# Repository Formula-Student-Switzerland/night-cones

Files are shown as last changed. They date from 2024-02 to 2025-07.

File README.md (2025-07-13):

# FSCH Night-Cones
FSCH night-cones

The FSCH Night-Cones are ESP8266 controlled RGB lights for the illumination of a formula student track. The project is described in detail in the documentation available in the `doc` folder. 

## Hardware

### PCBs

#### NC1-1
Nightcone main PCB

##### NC1-1AA
Initial prototype PCB as ordered

##### NC1-1AB
Modifications to the assembly of the initial prototype

##### NC1-1BA
PCB version for first series production run

##### NC1-1BB
Modifications to first series prodction run, version used in FSCH 2024 night skidpad

##### NC1-1CA
All issues from previous versions implemented. 
This version should be used for reproduction of the NightCones. 

##### Assembly variants
Multiple versions of the WS2813 LED exist, which have a slightly different pinout. This is covered by the different assembly variants of the PCB. 

###### NC1-11
WS2813B-B: 
* Pin 1 is VCC
* DATA_IN is connected to BACKUP_OUT
* VCC pin is supplied with a 270 Ohm resistor and bypassed with a 1uF capacitor

###### NC1-12
WS2813B-V5:
* Pin 1 is BO
* The BO pin and is connected to BACKUP_OUT

###### NC1-13
WS2813C:
* Pin 1 is VCC
* DATA_IN is connected to BACKUP_OUT
* VCC pin is supplied with a 270 Ohm resistor and bypassed with a 1uF capacitor

###### NC1-14
WS2813E:
* Pin 1 is NC
* DATA_IN is connected to BACKUP_OUT

#### NC1-2
Testadapter for automated PCB test of the main nightcone PCB NC1-1. Only index NC1-2BA exists, which is intended to be used for NC1-1B*. 

#### NC1-3
Programming adapter to program the nightcone PCB standalone as well as mounted in the enclosure. To program, a USB-A to UAB-B cable and a 6-pin RJ-11 TagConnect cable are required. 

### Housing
The current housing is designed to be printed out of transparent PETG. It consists of three parts that are printed independently and glued together afterwards. 

## Software
The current software state includes a running software on the cone. Currently, there exists no software running on server side.

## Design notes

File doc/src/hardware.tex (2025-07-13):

\section{Hardware}

\FloatBarrier

\subsection{Overview}

\FloatBarrier

\subsection{Controller}
\label{sec_ctrl}
An ESP8266 on a module is selected as microcontroller. The module is used as it already contains the matching network and either an antenna or antenna connector. 
The usage of an ESP32 was considered as well but finally rejected due to the higher cost. 

Three options are considered for the module: ESP-01S, ESP-07S and ESP-12F. \autoref{tab_ESP_modules} lists the modules and their most important specifications. 

\begin{table}[h!]
    \centering
    \begin{zebratabular}{llll}
    \rowcolor{gray} 
        Module  & GPIO  & ADC pin   & Antenna \\
        ESP-01S & 4     & No        & internal \\
        ESP-07S & 11    & No        & external \\
        ESP-12F & 17    & No        & internal \\
    \end{zebratabular}
    \caption[Overview of ESP6288 modules]
            {Overview of ESP6288 modules \cite{AIThinker:ESP_01S} \cite{AIThinker:ESP_07S} \cite{AIThinker:ESP_12F}}
    \label{tab_ESP_modules}
\end{table}

It is possible to solder any of the modules that is listed in \autoref{tab_ESP_modules} on the PCB. The ESP-07S can be soldered on the same footprint as the ESP-12F. The ESP-01S footprint could be fitted inside the ESP-12F footprint. Special car must be taken in that case, as the ESP-07S has an exposed pad. Only the GND pin of the ESP-01S is allowed to touch the area of the exposed pad to prevent short-circuits when the ESP-07S is mounted. \cite{AIThinker:ESP_07S}\cite{AIThinker:ESP_12F}

The ESP module is powered directly from the \qty{3.3}{\volt} supply. The design of the \qty{3.3}{\volt} supply is documented in \secref{sec_power_3V3}. 

The EN pin and the RST pin are pulled to \qty{3.3}{\volt} with a pull-up resistor each. The GPIO pinout is listed in \autoref{tab_ESP_pinout}. 

\begin{table}[h!]
    \centering
    \begin{zebratabular}{lllll}
        \rowcolor{gray} 
        Signal      & ESP-01S   & ESP-07S   & ESP-12F   & Description \\
        DATA        & GPIO0     & GPIO15    & GPIO15    & LED data \\
        KILL        & GPIO2     & GPIO13    & GPIO13    & Turn-off command \\
        HALL        & N/A       & GPIO14    & GPIO14    & Presence detection from hall sensor \\
        VBAT\_MON   & N/A       & ADC       & ADC       & Battery voltage monitor \\
    \end{zebratabular}
    \caption{ESP module pinout}
    \label{tab_ESP_pinout}
\end{table}

\FloatBarrier

\subsection{LED}
\label{sec_LED}
Addressable NeoPixel acp{LED} of the type WS2813 from WorldSemi are used to illuminate the cone. Four \acp{LED} are evenly distributed on the top side of the PCB to illuminate the enclosure of the NightCone. A total of 16 \acp{LED} are aligned in the shape of a circle on the bottom side. The purpose of those \acp{LED} is the illumination of the ground around the cone and the cone from above. 

Each NeoPixel \ac{LED} contains a controller and three single \acp{LED} in the colors red, green and blue. The brightness of each LED can be set through an interface. On the interface a bit is represented by a pulse. The value of the bit is encoded in the pulse length. A reset command is sent by pulling the data line low for an certain time $t_{reset}$. \autoref{fig_neopixel_bit} shows the signal shape of 0s, 1s and the reset pulse. The specific timing depends on the LED type and is listed in \autoref{tab_neopixel_timing}. \cite{Worldsemi:WS2813B-B}\cite{Worldsemi:WS2813B-V5}\cite{Worldsemi:WS2813C}\cite{Worldsemi:WS2813E}

\begin{figure}[h!]
    \centering
    \begin{tikztimingtable}
        0s    & 0.2L25{0.6H1.4L}0.2H\\
        1s    & 0.2L25{1.4H0.6L}0.2H\\
        Reset & 0.2H50L0.2H\\
    \end{tikztimingtable}
    \caption[NeoPixel bits, timing not representative]
            {NeoPixel bits, timing not representative, see \autoref{tab_neopixel_timing} for exact timing}
    \label{fig_neopixel_bit}
\end{figure}

\begin{table}[h!]
    \centering
    \begin{zebratabular}{lllllll}
        \rowcolor{gray}
        LED type    & $t_{0_H}$ [\si{\nano\second}] & $t_{0_L}$ [\si{\nano\second}] & $t_{1_H}$ [\si{\nano\second}] & $t_{1_L}$ [\si{\nano\second}] & $t_{Reset}$ [\si{\micro\second}]  & Pin 1 \\
        WS2813B-B   & 220 \ldots 380                & 580 \ldots 1600               & 580 \ldots 1600               & 220 \ldots 420                & > 280                             & VCC   \\
        WS2813B-V5  & 220 \ldots 380                & 580 \ldots 1000               & 580 \ldots 1600               & 580 \ldots 1000               & > 280                             & BO    \\
        WS2813C     & 220 \ldots 380                & 580 \ldots 1600               & 580 \ldots 1600               & 220 \ldots 420                & > 280                             & VCC   \\
        WS2813E     & 220 \ldots 380                & 580 \ldots 1600               & 580 \ldots 1600               & 220 \ldots 420                & > 280                             & NC    \\
    \end{zebratabular}
    \caption[LED timing overview]
            {LED timing overview \cite{Worldsemi:WS2813B-B}\cite{Worldsemi:WS2813B-V5}\cite{Worldsemi:WS2813C}\cite{Worldsemi:WS2813E}}
    \label{tab_neopixel_timing}
\end{table}

Each \ac{LED} has an internal buffered shift-register with a length of \qty{24}{\bit}. Every bit that is received shifts the content of the register for \todo{better word (um)} one bit. The last bit that is shifted out of the register is transmitted to the successive \ac{LED} in the chain. When a reset signal is received, the content of the shift-register is loaded into the buffer and the brightness of the three colored \acp{LED} is updated. The register definition is shown in \autoref{tab_neopixel_register}. \cite{Worldsemi:WS2813B-B}\cite{Worldsemi:WS2813B-V5}\cite{Worldsemi:WS2813C}\cite{Worldsemi:WS2813E}

\begin{table}[h!]
    \centering
    \begin{tabular}{|l|l|l|l|l|l|l|l|l|}
        \hline
        Bit     & 1  & 2  & 3  & 4  & 5  & 6  & 7  & 8  \\
        \hline
        Data    & G7 & G6 & G5 & G4 & G3 & G2 & G1 & G0 \\
        \hline
        \hline
        Bit     & 9  & 10 & 11 & 12 & 13 & 14 & 15 & 16 \\
        \hline
        Data    & R7 & R6 & R5 & R4 & R3 & R2 & R1 & R0 \\
        \hline
        \hline
        Bit     & 17 & 18 & 19 & 20 & 21 & 22 & 23 & 24 \\
        \hline
        Data    & B7 & B6 & B5 & B4 & B3 & B2 & B1 & B0 \\ 
        \hline
    \end{tabular}
    \caption{NeoPixel register definition}
    \label{tab_neopixel_register}
\end{table}

The advantage of the WS2813 type over the widely used WS2812 is the additional backup input. The input of each \ac{LED} is also connected to the backup input of the next \ac{LED} in the chain. This allows the chain to continue operation even when a \ac{LED} has failed completely. The chain continues to operate with up to half of the \acp{LED} failed, as long as there are no successive failed \acp{LED}. On some \ac{LED} types a separate backup output exists on pin 1. Refer to \autoref{tab_neopixel_timing} for this information. 

\subsection{Failsafe}
\label{sec_failsafe}
\ReqRef{R:Failsafe} requires the \acp{LED} to illuminate in a controlled way after a controller failure. The simplest way to control the \acp{LED} is to send 1's followed by a reset pulse. This causes the \acp{LED} to light up white with the highest intensity. To ensure that all \acp{LED} turn on, the number of bits sent must be at least the number of bits per \ac{LED} multiplied by the number of \acp{LED}. A missing-pulse detector with an edge detector is used to detect a controller failure. Depending on the state of this detector, the signal from the controller or the failsafe signal is selected for the \acp{LED}. 

The controller is powered with a voltage of \qty{3.3}{\volt}, which results in the same level for the output signals. The \acp{LED} are powered by the \qty{5.2}{\volt} supply and therefore expect an input signal with a similar voltage. A level-shifter converts the signal from \qty{3.3}{\volt} to \qty{5.2}{\volt} and also inverts the signal. An edge-detector avoids that a static signal triggers the missing-pulse detector. The inverter of the edge-detector is used to recondition the input signal and invert it again. The edge-detector generates a low pulse when a rising edge is detected. \autoref{fig_failsafe_edge}

\begin{figure}[h!]
    \centering
    
    \caption{Levelshifter and edge detector}
    \label{fig_failsafe_edge}
\end{figure}

The missing-pulse detector is built with a XL555, which is a pin-compatible \ac{CMOS} derivate of the NE555 timer. \todo{reference to XL555 datasheet} The timing capacitor C10 is continuously charged by R13. The low pulse from the edge-detector discharges the capacitor through D10 and R20. R20 limits the current to protect the output of the edge-detector. In case D10 is not able to discharge C10 quick enough, Q4 can be added to increase the discharge current. The output of the edge-detector is also connected to the TRIG input of the timer and sets the internal flipflop when a pulse is detected. When the capacitor voltage reaches the CONT voltage, which is $\frac{2}{3}$ of the supply voltage, the flipflop of the timer is reset, which is interpreted as controller-failure. \autoref{fig_failsafe_missing_pulse}

\begin{figure}[h!]
    \centering
    
    \caption{Missing-pulse detector}
    \label{fig_failsafe_missing_pulse}
\end{figure}

An astable multivibrator with a XL555 generates the pulse pattern for a series of 1s. The timing requirements depends on the \ac{LED} type. \autoref{tab_neopixel_timing} shows the timing requirements for each \ac{LED} type that can be used. The formula for the timing as astable multivibrator is inaccurate in the frequency range that is used to generate the data pulse. \todo{Reference to XL555 datasheet} Therefore the component values for the oscillator were iterated on a test circuit using a TLC555 which is very similar to the XL555 that is used. The resulting values are listed in \autoref{tab_failsafe_bit_values}. The bit signal is fed into a ripple counter to count the number of bits and generate the reset pulse. \todo{Number of stages in the reset counter} \autoref{fig_failsafe_bit_counter}

\begin{table}[h!]
    \centering
    \begin{zebratabular}{llllll}
        \rowcolor{gray}
        LED &
        $t_{1_H}$ &
        $t_{1_L}$ &
        R17 &
        R19 &
        C11 \\
        B-B, C, E &
        \qty{1.09}{\micro\second} &
        \qty{320}{\nano\second} &
        \qty{1.5}{\kilo\ohm}   &
        \qty{270}{\ohm}        &
        \qty{470}{\nano\farad} \\
        B-V5 &
        \qty{1.09}{\micro\second} &
        \qty{790}{\nano\second} &
        \qty{910}{\ohm} &
        \qty{1.2}{\kilo\ohm} &
        \qty{470}{\nano\farad} \\
    \end{zebratabular}
    \caption{Component values for the astable multivibrator, obtained from TLC555 test circuit iteration}
    \label{tab_failsafe_bit_values}
\end{table}

\begin{figure}[h!]
    \centering
    
    \caption{Bit-pulse generator with counter for reset generation}
    \label{fig_failsafe_bit_counter}
\end{figure}

The data pulse and the reset signal are combined to the failsafe signal with an AND gate. A multiplexer (74LVC1G157) selects either the signal from the controller or the failsafe signal to send to the \acp{LED} based on the state of the missing-pulse detector. 

\begin{figure}[h!]
    \centering
    
    \caption{Signal selector}
    \label{fig_failsafe_mux}
\end{figure}

\FloatBarrier

\subsection{Battery}
\label{battery}
The NightCone is powered by a single \ac{LiIon} battery cell. The cell is mounted in the center of the NightCone. 

To design the required battery capacity, the energy consumption of each component is calculated. The efficiency $\eta_{5V2}$ and $\eta_{3V3}$ of each voltage converter is assumed to be 0.9. 

The average current consumption of the ESP module is \qty{71}{\milli\ampere} at a supply voltage of \qty{3.3}{\volt}. \cite{AIThinker:ESP_12F}
\begin{align}
    P_{ESP} = \dfrac{V_{ESP} \cdot I_{ESP}}{\eta_{5V2} \cdot \eta_{3V3}} = \dfrac{\qty{3.3}{\volt} \cdot \qty{71}{\milli\ampere}}{0.9 \cdot 0.9} = \qty{289.3}{\milli\watt}
\end{align}

The current of a single \ac{LED} is up to \qty{16}{\milli\ampere} for all three colors. \cite{Worldsemi:WS2813E}
\begin{align}
    P_{LED} = \dfrac{V_{LED} \cdot I_{LED} \cdot 3 \cdot n_{LED}}{\eta_{5V2}} = \dfrac{\qty{5.2}{\volt} \cdot \qty{16}{\milli\ampere} \cdot 3 \cdot 20}{0.9} = \qty{5.547}{\watt}
\end{align}

As the current consumption of the failsafe circuit is assumed to be much smaller than that of the \acp{LED} it is neglected for the energy estimation. 

The minimum oparation time is defined in \ReqRef{R:Time}. 
\begin{align}
    W = \left(P_{ESP} + P_{LED}\right) \cdot t = \left(\qty{289.3}{\milli\watt} + \qty{5.547}{\watt}\right) \cdot \qty{4}{\hour} = \qty{23.35}{\watt\hour}
\end{align}
\begin{align}
    Q = \dfrac{W}{V_{nom}} = \dfrac{\qty{23.35}{\watt\hour}}{\qty{3.6}{\volt}} = \qty{6.31}{\ampere\hour}
\end{align}

A capacity of \qty{6.31}{\ampere\hour} would require a 26650 cell. As the cone is not expected to be set to the maximum brightness for all three colors, a capacity of about \qty{5}{\ampere\hour} is expected to be sufficient. This allows the use of a 21700 cell, which reduces the cost of the battery solution. A 18650 cell could also fit in the enclosure, but would only be available with a capacity of \qty{3}{\ampere\hour}, which is assumed to be insufficient. 

The cell is mounted in the center of the NightCone. The \ac{PCB} includes an opening in the center for the cell to fit through. Nickel strips are spotwelded to the cell. The strips are soldered to solder pads to connect the battery to the electronics. The positive lead is connected soldered to the top side of the \ac{PCB}, the negative lead to the bottom side. 

\subsection{Battery Management System}
\label{sec_bms}
The battery management system is pretty simple using a two IC solution. The used DW01A \cite{Puolop:DW01A} is a low cost \ac{LiIon} protection IC. It protects the battery from the following issues: 
\begin{itemize}
	\item Overvoltage at $\qty{4.3(0.05)}{\V}$  after $\qtyrange{110}{200}{\ms}$
	\item Undervoltage at $\qty{2.50(0.10)}{\V}$after $\qtyrange{55}{200}{\ms}$
	\item Overcurrent
\end{itemize}
This covers requirement \ReqRef{R:Current} and partially \ReqRef{R:BMS}. The overtemperature protection is done in the charger and therefore only available during charging. 

The overcurrent protection is realized using the voltage drop over the two AO3400A \cite{AOSMD:AO3400A}. The DW01A IC features two types of over current protection. 

The fast over current protection triggers at nominal $\qty{1.36}{\V}$ with a blanking time of $\qtyrange{400}{600}{\ms}$. This leads to the following thresholds: 
\begin{align}
	I_\mathrm{SC;fast,min} &= \frac{V_\mathrm{SC,fast,min}}{2\cdot R_\mathrm{AO3400A,max}}=\frac{\qty{0.82}{\V}}{2\cdot\qty{48}{\milli\ohm}}=\qty{8.5}{\A}\\
		I_\mathrm{SC;fast,typ} &= \frac{V_\mathrm{SC,fast,typ}}{2\cdot R_\mathrm{AO3400A,typ}}=\frac{\qty{1.36}{\V}}{2\cdot\qty{24}{\milli\ohm}}=\qty{28.3}{\A}\\
		I_\mathrm{SC;fast,max} &= \frac{V_\mathrm{SC,fast,max}}{2\cdot R_\mathrm{AO3400A,typ}}=\frac{\qty{1.75}{\V}}{2\cdot\qty{24}{\milli\ohm}}=\qty{36.5}{\A}\\
\end{align}

\begin{figure}[h!]
    \centering
    
    \caption{Battery management system}
    \label{fig_bms}
\end{figure}

The slow over current protection triggers at nominal $\qty{150(20)}{\milli\V}$ after a blanking time of $\qtyrange{7}{20}{\ms}$. This leads to the following values: 
\begin{align}
	I_\mathrm{SC;slow,min} &= \frac{V_\mathrm{SC,slow,min}}{2\cdot R_\mathrm{AO3400A,max}}=\frac{\qty{130}{\milli\V}}{2\cdot\qty{48}{\milli\ohm}}=\qty{1.4}{\A}\\
		I_\mathrm{SC;slow,typ} &= \frac{V_\mathrm{SC,slow,typ}}{2\cdot R_\mathrm{AO3400A,typ}}=\frac{\qty{150}{\milli\V}}{2\cdot\qty{24}{\milli\ohm}}=\qty{3.1}{\A}\\
		I_\mathrm{SC;slow,max} &= \frac{V_\mathrm{SC,slow,max}}{2\cdot R_\mathrm{AO3400A,typ}}=\frac{\qty{170}{\milli\V}}{2\cdot\qty{24}{\milli\ohm}}=\qty{3.5}{\A}\\
\end{align}

If the maximum current is $I_\mathrm{max}=\frac{P_\mathrm{ESP}+P_\mathrm{LED}}{V_\mathrm{bat,min}}=\frac{\qty{289.3}{\milli\W} + \qty{5.547}{\W}}{\qty{2.5}{\V}}=\qty{2.33}{\A}$, the current threshold is exceeded, if the resistance of both MOSFETS is at the maximum value. This must be extensively tested. 

The resettable fuse acts as a last resort, if the DW01A is malfunctioning.

\FloatBarrier

\subsection{Charger}
\label{sec_charger}

The cone can be charge by using three screws as connectors on the outside to fulfil \ReqRef{R:Charging}. Two of the three circumferentially distributed screws must be connected to a voltage of $\qtyrange{5.25}{6.5}{\V}$, as it can be seen in Figure \ref{fig_chg_connection}. 
\begin{figure}[h!]
	\centering
	
	\caption{Charging pin connection}
	\label{fig_chg_connection}
\end{figure}
The $\qty{1.5}{\A}$ fuse protects the charging circuit. The six shottky rectifier diodes allow to use any pin for positive and negative supply. The two $\qty{1}{\ohm}$ resistors are used to reduce the required voltage drop inside the charging IC and to act as linear impedance for the $\qty{6.8}{\V}$ transient voltage suppression diode. The diode has a reverse stand-off voltage of $\qty{5.8}{\V}$ and a minimum breakdown voltage of $\qty{6.45}{\V}$. 
This allows a maximum input voltage of 
\begin{align}
	V_\mathrm{in,max} &= V_\mathrm{R,TVS} + 2\cdot V_\mathrm{f,SS34} = \qty{5.8}{\V}+ 2\cdot \qty{0.35}{\V}=\qty{6.5}{\V}\\
	V_\mathrm{in,min,end} &= V_\mathrm{bat,max} + V_{drop, TP4056} + 2\cdot V_{f,SS34} = \qty{4.2}{\V} + \qty{0.03}{\V} + 2\cdot \qty{0.35}{\V} = \qty{4.93}{\V}
\end{align}
The voltage drop on the voltage reduction resistor can be neglected for the first two cases because the maximum voltage must be followed also for the final charge phase, where the current converges to zero and the same is the case for the minimal voltage when finishing charging. 
The voltage drop is considered in the following case for the minimum voltage at full charging current at the highest voltage:
\begin{align}
	V_\mathrm{in,min,charge} &= V_\mathrm{bat,charge} + V_\mathrm{drop, TP4056} + 2\cdot V_\mathrm{f,SS34} + R \cdot I_\mathrm{chg}\\
	&= \qty{4.1}{\V} + \qty{0.03}{\V} + 2\cdot \qty{0.35}{\V} + \qty{0.5}{\ohm} \cdot  \qty{0.78}{\A} = \qty{5.22}{\V}
\end{align}

\begin{figure}[h!]
    \centering
    
    \caption{Charging rectifier and input protection}
    \label{fig_chg_input}
\end{figure}

The charging IC TP4056 \cite{MSKSEMI:TP4056} monitors the cell temperature during the charging process by evaluating the voltage drop of the used $\qty{10}{\kilo\ohm}$ \ac{NTC}. This covers the missing part of \ReqRef{R:BMS}. The voltage at the Temp pin is evaluated as ratio to the supply voltage. The operative range is $\num{0.45} \cdot \mathrm{VCC}$ to $\num{0.8} \cdot \mathrm{VCC}$. The resistor divider is designed to operate in a temperature range from $\qtyrange{5}{50}{\celsius}$. The resistors $R_5$ and $R_7$ are derived using these formulas: 
\begin{align}
R_7 &= \frac{R_\mathrm{th,low}\cdot R_\mathrm{th,high}}{(V_\mathrm{th,low}-1)\cdot R_\mathrm{th,high} + \left(\frac{V_\mathrm{th,low}}{V_\mathrm{th,high}}-V_\mathrm{th,low}\right)\cdot R_\mathrm{th,low}}\\
R_5 &= R_7\cdot R_\mathrm{th,low}\cdot \frac{1-V_\mathrm{th,high}}{V_\mathrm{th,high}\cdot (R_7+R_\mathrm{th,low})}
\end{align}
The resulting values where then adapted to use resistors already used in other parts of the schematic, which also matched quite well. 

\begin{figure}[h!]
    \centering
    
    \caption{Charger}
    \label{fig_charger}
\end{figure}

The charging current is set to $\qty{780}{\mA}$ by using the $\qty{1.5}{\kilo\ohm}$ resistor. The charger has a trickle current feature that charges the battery with a low current of $\qty{130}{\milli\A}$ if the battery voltage is below $\qty{2.9}{\V}$. \\
In the schematic, both \acp{LED} are marked as green. \ac{LED} D6 is replaced by a red \ac{LED}. The functions of the \acp{LED} are summarized in the following table

\begin{table}[h!]
    \centering
    \begin{zebratabular}{lll}
        \rowcolor{gray}
        Charging State &
        LED Green &
        LED Red \\
        Charging & off & on \\
        Charging terminated & on & off\\
        Temp error, no power or battery & off &off\\
        No battery & on & flashing ($\qtyrange{1}{4}{\s}$)
    \end{zebratabular}
    \caption{Charger LED Signals}
    \label{tab_chg_led}
\end{table}

\FloatBarrier

\subsection{On/off controller}
\label{sec_onoff}

As \ReqRef{R:Rain} requires the cone to be able to operate in rain , it must be possible to turn the NightCone on and off without opening it. To fulfill this requirement, one method to enable the NightCone and two methods to disable it are implemented. The hall sensor U30 (UHE4913) detects the presence of a magnet. When a magnet is detected, the output of the sensor is pulled low. This pulls the enable input of the boost converter U28 towards the battery voltage, which enables the converter. As the hall sensor is directly connected to the battery and therefore always powered, a sensor with a low operating current must be chosen. The selected boost converter (TPS61023) completely disconnects the output from the input when the converter is disabled. This is necessary because the output voltage of a boost converter is always at least slightly lower than the input voltage due to the body diode of the highside \ac{MOSFET}. \cite{TI:TPS61023}. \todo{Check link to TPS61023 datasheet}

The controller can send a KILL signal to the on/off controller. To ensure, that a static high signal is not able to shut down the NightCone, the signal is AC coupled and rectified. To disable the NightCone, a series of pulses must be sent to the KILL signal which charges the capacitor C71. When the threshold voltage of Q10 is reached, the \qty{5.2}{\volt} converter is disables by pulling the EN signal low. 

The requirement \ReqRef{R:Disable} demands an analog shutdown device. This is implemented by supervising the voltage on the charging input. When a voltage is detected, Q9 pulls the EN signal to GND, which disables the \qty{5.2}{\volt} converter. The threshold level can be adjusted by changing the voltage divider R94 and R96. This ensures that the NightCone is automatically disabled when it is connected to the charging station. 

During development and debugging it is advantageous to allow the operation of the NightCone while the battery is being charged. To allow this operation mode, the signal of the hall sensor is prioritized over both turn off signals. This means, that the NightCone can not be turned off when the presence of a magnet is detected. For the schematic of the on/off controller, see \autoref{fig_onoff}. 

\begin{figure}[h!]
    \centering
    
    \caption{On/off controller}
    \label{fig_onoff}
\end{figure}

\FloatBarrier

\subsection{Converter \qty{5.2}{\volt}}
\label{sec_power_5V2}

\begin{figure}[h!]
    \centering
    
    \caption{\qty{5.2}{\volt} converter}
    \label{fig_power_5V2}
\end{figure}

\FloatBarrier

\subsection{Converter \qty{3.3}{\volt}}
\label{sec_power_3V3}

\begin{figure}[h!]
    \centering
    
    \caption{\qty{3.3}{\volt} converter}
    \label{fig_power_3V3}
\end{figure}

\FloatBarrier

\subsection{Testing}
The initial prototypes (index A) are manually tested using the protocol in \todo{Add test protocol to annex and refer to it}. 

For the production run with index B, a test adapter is built to allow for automated testing. 

\begin{table}[h!]
    \centering
    \begin{zebratabular}{lllll}
        \rowcolor{gray}
        Testpoint   & Signal    & Measure       & Supply        & Short         \\
        TP1         & Data      &               & Pulse 3V3     & GND           \\
        TP2         & GPIO0     &               & Programmer    & GND           \\
        TP3         & SDA       &               &               &               \\
        TP4         & SCL       &               &               &               \\
        TP5         & KILL      &               & Pulseburst 3V3&               \\
        TP6         & TXD       &               & Programmer    &               \\
        TP7         & RXD       &               & Programmer    &               \\
        TP8         & RST       & Voltage       & Programmer    & GND           \\
        TP9         & TEMP      & Voltage       &               &               \\
        TP10        & FS\_ACT/  & Voltage       &               &               \\
        TP11        & DATA\_FS  & Pulsewidth    & Pulse 5V      & GND           \\
        TP12        & FS\_PULSE & Pulsewidth, f &               &               \\
        TP13        & FS\_DATA  & Pulsewidth, n &               &               \\
        TP14        & +5V\_CHG  & Voltage       &               &               \\
        TP15        & CHG\_A    &               & Charge +/-    &               \\
        TP16        & CHG\_B    &               & Charge +/-    &               \\
        TP17        & CHG\_C    &               & Charge +/-    &               \\
        TP18        & +VBAT     & Voltage Bat   & Battery +     & Load to -VBAT \\
        TP19        & -VBAT     & Voltage Bat   & Battery -     & Load to +VBAT \\
        TP20        & +5V2      & Voltage       &               & Load to GND   \\
        TP21        & +3V3      & Voltage       &               & Load to GND   \\
        TP22        & GND       &               &               &               \\
        TP23        & HALL/     & Voltage       &               & GND           \\
        TP24        & VBAT\_MON & Voltage       &               &               \\
    \end{zebratabular}
    \caption{NC1-1B test point overview}
    \label{tab_test_point}
\end{table}

\FloatBarrier

\subsection{Modifications from index AA to index AB}

\subsubsection{Feedforward capacitor in \qty{5.2}{\volt} and \qty{3.3}{\volt} supply}
The feedforward capacitors in the feedback networkof the two converters are not meant to be mounted. It must either be removed or a value must be selected to ensure loop stability. 

\subsubsection{Charging LED color}
To reduce the cost of the first prototypes, the color of the charging \ac{LED} was changed to green. For correct operation, it needs to be changed to red. 

\subsection{Modifications from index AA to index BA}

\subsubsection{Programming connector}
A Tag-Connect interface (TC2030) should be added for programming the ESP module. If there is enough space, the footprint with legs should be used. Necessary signals are TX, RX, RESET and GIPO0. 

\subsubsection{ESP-01S}
The GPIO count of the ESP-01S is insufficient for the complete functionaility and it lacks an \ac{ADC} input. The option to mount it can therefore be removed. 

\subsubsection{Memory for configuration data}
To reduce the number of write cycles on the flash memory of the ESP8266, an additional nonvolatile memory should be added to store configuration data. It needs to be able to endure frequent write operation. From a first analysis, an \ac{I2C} \ac{EEPROM} would be ideal. 

\subsubsection{GPIO}
Due to the addition of an \ac{I2C} \ac{EEPROM}, the \ac{GPIO} pins need to be rearranged, as on index A, the signal from the hall sensor is connected to GPIO14, which is used as SCL. 

\subsubsection{HW ID}
A hardware ID should be implemented to indicate different hardware revisions to the software. This can be implemented by connecting GPIO pins or by changing the I2C address of the EEPROM. No additional HW should be implemented for the HW ID. 

\subsubsection{Over-current protection}
The over-current protection on the prototype triggers below the maximum current, because the maximum resistance of the used MOSFETs is to high. The typical value would be sufficient. The fuse $(\qty{1.5}{\A}$ is as well too low. 

\subsubsection{Failsafe counter output}
The failsafe counter only counts to 256. With a total of 20 \acp{LED}, 480 pulses are required to turn on all \acp{LED}. Therefore FS\_RESET must be connected to Q9 instead of Q8. 

\subsubsection{Quiescent current}
D11 causes about \qty{40}{\micro\ampere} of quiescent current (up to \qty{500}{\micro\ampere} according to datasheet) and is unnecessary as the body diode of Q5 is parallel. D11 can be removed. 

\subsubsection{Power indication LED}
The power indication \acp{LED} are unnecessary and can be removed or set to NB. 

\subsubsection{GPIO 15 for FW upload}
GPIO 15 must always be pulled low for Flash boot and FW upload. R16 must be replaced by a $\qty{10}{\kilo\ohm}$ for the prototype and should not be used for the next version. Move DATA signal to another pin. 

\subsubsection{Low time of Failsafe pulse generator}
The low time of the failsafe pulse generator is too high. A value of \qty{532}{\nano\s} is measured. A value of \qty{320}{\nano\s} is targeted. 

\subsubsection{Power indication LED}
The power indication \acp{LED} D14 and D15 are not needed and can be removed. 

\subsubsection{Testpoints at end of LED chain}
The testpoints at the end of the \ac{LED} chain are not used and can be removed. The resistors for routing the backup signal around the last LED can be removed as well. 

\subsubsection{Voltage measurement filtering}
The voltage divider for the battery voltage measurement is not filtered. A capacitor should be placed on VBAT\_MON. 

\subsubsection{Temperature measurement}
During the first tests at full brightness, a temperature of over \qty{62}{\celsius} was observed. When the \ac{PCB} is mounted inside the enclosure, an even higher temperature is expected. Therefore a means to observe the internal temperature should be implemented. The control module has only one \ac{ADC} input which is already used to measure the cell voltage. A multiplexer could be used to switch the analog input between voltage and temperature measurement. Another option would be the use of a temperaure sensor with a digital interface. 

\subsubsection{On/Off controller feedback capacitor}
The feedback capacitor of the On/Off Controller is not needed and can be removed. 

\subsubsection{Charging port testpoint}
Additional testpoints should be added to the charging ports to ease the connection with the test adapter. 

\subsubsection{Testpoint labels on top layer}
The testpoints are only labelled on the bottom layer. To ease testing and debugging, the testpoints should be labelled on the top layer as well. 

\subsection{Modifications from index BA to index BB}

\subsubsection{Level shifter too slow}
The rise time of the level shifter is too long. R18 should be changed from 1K5/0603 to 270R/0603. In addition, R3 should be changed from 270R/0603 to 0R/0603. 

\subsubsection{Edge detector not working}
The edge detector is not working because the time constant of the delay is too long. R21 should be changed from 100K/0603 to 3K3/0603 and C6 should be changed from 1U/0603 to 100P/0603. 

\subsubsection{Unreliable magnet turn-off}
The turn-off with a magnet using the hall sensor is unreliable. This is caused by the low threshold voltage of the EN pin of the boost converter U30 (TPS61023) in combination with the voltage drop over R104 and D13. The value of R104 should be changed from 1K5/0603 to 620R/0603. 

\subsubsection{EEPROM not accessible}
No pull-up resistors are placed on the \ac{I2C} lines and the internal pull-up resistors of the ESP module are too weak. Additional pull-up resistors are to be placed from SDA and SCL to +3V3. 

\subsubsection{Software shut-down not working}
The software shut-down does not work, because the voltage that is generated on the \ac{MOSFET} Q10 is insufficient to shut down the \qty{5.2}{\volt} converter. This reduction in voltage is caused by the voltage divider that is formed with the resistors R9 and R110. R9 can not be removed, as it is essential for allow automated testing of the shutdown circuit. The resistor R110 is replaced with a schottky diode 1N5819WS. 

\subsection{Modifications from index BB to index CA}

\subsubsection{Level shifter distorts duty cycle}
Rise and fall time of the level shifter are not identical. This leads to a distortion of the duty cycle of the DATA signal. In the first series production this was corrected by adjusting the pulse width in the neopixel library. 
For a new production run, the level shifter should be changed to a type that does not introduce any distortion in the signal duty cycle. 
The inverter 74HCT1G04, which accepts TTL levels, should work. 

\FloatBarrier

\subsection{Programmer NC1-3AA}
\label{Programmer_Hardware}
Programming the ESP-12F module requires the assertion of GPIO 0 and pulling the reset line. To simplify programming and configuration of the night-cones, a dedicated programmer was developed. This programmer is based on an FTDI FT234XD \cite{FTDI:FT234XD}. The hardware for it is straight forward. The reset pin of the ESP is connected to the \texttt{RTS} pin of the FT234XD. The \texttt{GPIO 0} used to switch between the normal boot mode and bootloader mode is connected to the \texttt{CBUS 0} pin. The \texttt{TX} and \texttt{RX}. \textbf{For a future design, a chip with native RTS and DSR support should be used!}

The chip is then reprogrammed using the \texttt{FT\_PROG} Tool to exhibit the correct name, driver configuration and to use the CBUS0 pin as GPIO. This is shown in figure \ref{fig_nc31AA_config}. 

On Windows an additional step is needed. However keep in mind, that this could create problems with FTDI chips in future. Refer to the last subsection to revert the changes. 
\begin{figure}
		\centering
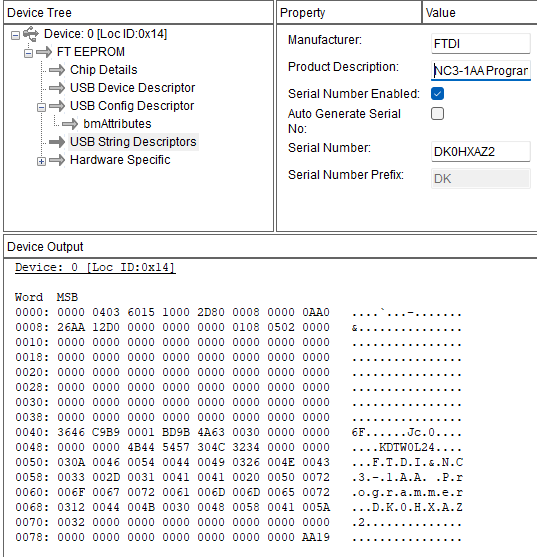
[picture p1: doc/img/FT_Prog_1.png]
		
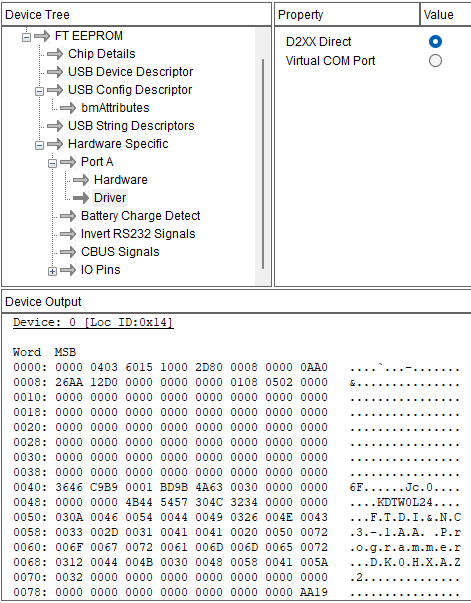
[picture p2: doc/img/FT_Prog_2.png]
		
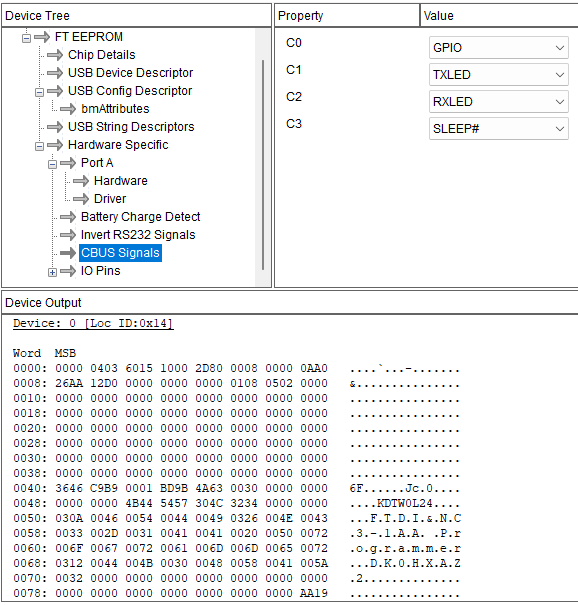
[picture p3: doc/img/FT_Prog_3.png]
		
		\caption[FT\_Prog Configuration]{FT\_Prog configuration for NC3-1AA Programmer. The Product Description is \texttt{NC3-1AA Programmer}.}
		\label{fig_nc31AA_config}	
\end{figure}

\subsubsection{Zadig Configuration}
The python script of the modified programmer (refer to \ref{programmer_software}) uses the pyftdi library, which in terms uses the libwinusb-32 library. On linux, this driver is natively available. On Windows machines, this needs to be manually assigned. Zadig\cite{zadig} is a freeware tool used to change the \ac{USB} driver of a specific device. Change the driver of the \texttt{NC3-1 Programmer} to libwinusb-32. It could be necessary to enable \texttt{List All Devices} in the \texttt{options} menu. After installing the driver, you are ready to program the night-cones using the NC3-1AA Programmer. 

\subsubsection{Revert Zadig configuration}
To revert the changes made by Zadig, the driver needs to be uninstalled using the Windows Device Manager. The driver can be removed using a right click on the NC3-1AA Programmer Entry. 

\FloatBarrier

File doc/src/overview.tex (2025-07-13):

\section{Overview}
\lipsum

\subsection{Mechanical Design}

\FloatBarrier
\subsection{EMI Concept}
There is no EMI concept available. Therefore, this section remains empty. 

\FloatBarrier
\subsection{Interfaces}
The cones have two electrical and one radio interface. The cone can be charged using any two of the three screws at the bottom by applying a voltage between \qty{5.5}{\V} and \qty{10}{\V}. A higher voltage leads to higher losses on the board. A Voltage of \qty{6}{\V} is suggested. 

The second electrical interface is used for programming and command line access. The used ESP8266 is programmed through serial UART, which can be used as a simple command line interface as well. In addition, the reset signal and GPIO0 are also available on this TAG-Connect interface. 

The cone integrates a WIFI interface, which is used for communication to the server and can as well be used to update the software over-the-air.

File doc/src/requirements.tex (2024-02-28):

\section{Requirements}

\subsection{Functional requirements}
\begin{table}[h!]
    \begin{ReqTable}
    \ReqHeader
    \ReqItem{R:Cone}{The NightCone can be mounted on top of a cone as used in formula student events. \cite{FSG:Rules_2024}}
    \ReqItem{R:Light}{The NightCone illuminates the cone underneath and its enclosure sufficient to be seen at dusk and night. The cone should be easily visible from a normal driving position and by track marshals. }
    \ReqItem{R:Power}{The NightCone is internally powered. }
    \ReqItemMM{R:Time}{The cone runs for the estimated time of a skidpad or acceleration event}{$\qty{4}{\hour}$}{N/A}
    \ReqItem{R:Color}{The color of the NightCone can be adjusted. }
    \ReqItem{R:Blink}{Simple light modes (eg. Blinking) can be set. }
    \ReqItem{R:Control}{A centralized control system (eg. Laptop, smartphone) is capable of controlling the NightCones. }
    \ReqItem{R:Usability}{An untrained person is capable of using the system after the initial setup is completed. }
    \ReqItem{R:Disable}{All components can be disabled by the means of an analog shut-down device. }
    \ReqItem{R:Flying}{The change in mass and center of gravity does not lead to a significant change in the flying characteristics of the cone. }
    \ReqItem{R:Charging}{When a battery is used to power the cone, the battery can be charged without opening the enclosure. }
    \end{ReqTable}
\end{table}

\clearpage

\subsection{Safety requirements}
\begin{table}[h!]
    \begin{ReqTable}
    \ReqHeader
    \ReqItem{R:Failsafe}{A failure of the controller leads to a defined safe-state. The safe-state must provide at least a minimum amount of illumination. }
    \ReqItem{R:Change}{An unintended change of the color setting must be prevented. }
    \ReqItem{R:Short}{A short circuit of the battery or the charging port must be prevented. }
    \ReqItem{R:Current}{The NightCone must include overcurrent protected on for the battery. }
    \ReqItem{R:BMS}{The battery must be protected against deep-discharge, over-charge and over-temperature. }
    \ReqItem{R:Rain}{The NightCone must be able to operate in rain. The enclosure fulfills an ingress protection of at least IP54. }
    \ReqItem{R:Crash}{The components of the NightCone are protected when the cone is hit by a car. The hit cone must not pose any additional danger. The functionality of the cone can be deteriorated after the impact. }
    \ReqItem{R:Edges}{The NightCone has no additional excessively sharp edges. }
    \ReqItem{R:Mass}{The additional mass must not pose an significantly increased danger. }
    \end{ReqTable}
\end{table}

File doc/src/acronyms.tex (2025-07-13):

\section*{Acronyms}
%\addcontentsline{toc}{section}{Abkürzungen}
\begin{acronym}[Acronyms]
    \acro{ADC}{analog digital converter}
    \acro{CRC}{cyclic reduncancy check}
    \acro{CMOS}{complementary metal oxide semiconductor}
    \acro{CT}{current transformer}
    \acro{FEM}{finite element method}
    \acro{DeltaSigma}[$\Delta\Sigma$]{delta-sigma}
    \acro{EEPROM}{electrically erasable programmable read only memory}
    \acro{ESD}{electro static discharge}
    \acro{ESR}{equivalent series resistor}
    \acro{GPIO}{general purpose input output}
    \acro{GUI}{Graphical User Interface}
    \acro{I2C}[I$^{2}$C]{inter-integrated circuit}
    \acro{IC}{integrated circuit}
    \acro{IO}[I/O]{input output}
    \acro{JSON}{JavaScript Object Notation}
    \acro{LED}{light emitting diode}
    \acro{LiIon}{lithium ion}
    \acro{LSB}{least significant bit}
    \acro{MAC}{Media Access Control}
    \acro{MOSFET}{metal oxide semiconductor field effect transistor}
    \acro{NTC}{Negative Temperature Coefficient Thermistor}
    \acro{OTA}{Over-the-Air}
    \acro{PCB}{printed circuit board}
    \acro{PLL}{Phase-Locked-Loop}
    \acro{PWM}{pulse width modulation}
    \acro{RMS}{root-mean square}
    \acro{RSSI}{Received Signal Strength Indication}
    \acro{RTC}{real time clock}
    \acro{SAR}{successive approximation register}
    \acro{SoC}{State of Charge}
    \acro{SI}{système international d'unités}
    \acro{SNR}{signal-to-noise ratio}
    \acro{TI}{Texas Instruments}
    \acro{UDP}{User Datagram Protocol}
\end{acronym}

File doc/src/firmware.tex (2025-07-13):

\section{Firmware}

The software is written in C++ using VS Code as IDE in combination with the PlatformIO extension. However, it is written in C style, not using classes.
The software is built from various modules described below.

\subsection{adc}
This module reads out the integrated ADC and switches between both channels after each conversion. The \texttt{adc\_loop} function needs to be called periodically to read out the conversion value. The values are afterwards stored in the variables \texttt{adc\_volt\_meas} and \texttt{adc\_temp\_deg}. 

The battery voltage is stored in millivolt. The temperature is stored in degrees. Additionally the \ac{SoC} is available in \texttt{adc\_soc} in percent. 
\subsection{cli}
The command line interface is only used to set the serial number and the hardware revision. The command line interface can be disabled if necessary using the compiler flag \texttt{CLI\_ENABLED}.
For this, the following commands are available: 
\begin{itemize}
	\item \texttt{help}: Prints a message to test the command line interface. 
	\item \texttt{LED}: Can be used to set the current lightmode. The command takes 4 positional arguments: \texttt{color}, \texttt{brightness}, \texttt{lightmode}, \texttt{repetition time}.
	\item \texttt{setLEDFallback}: This command can be used to set the fallback (default) lightmode that is used at turn on. It stores the current active lightmode as default. 
	\item \texttt{saveEEPROM}: Stores the current settings (hardware and user settings part) to the EEPROM. 
	\item \texttt{readEEPROM}: Reads out the EEPROM again and updates the config storage. 
	\item \texttt{setSerialNo}: Sets the serial number and the hardware revision to the config storage. To store the values in the EEPROM, \texttt{saveEEPROM} needs to be called. This commands takes the two arguments in decimal: \texttt{[serial number]}, \texttt{[hardware revision]}	
\end{itemize}

\subsection{config\_store}
The config storage is used to store data on the EEPROM mounted on nightcones starting with hardware revision \texttt{NC1-1B}. The EEPROM has a block syize of 8 bytes. Therefore the memory layout is aligned to the 8 byte boundaries. The memory consists of three blocks. The first block called header contains information about the config storage itself. The second block called hardware data contains information that can not be changed through the WLAN interface like the serial number and the hardware revision. The third block contains user settings and can be modified through the WLAN interface.  

The memory layout of the config storage is shown below: 
\begin{table}[ht!]
\begin{tabular}{|c|l|l|}
	\textbf{Byte} & \textbf{Name} & \textbf{Description}\\\hline
	0 & PSVN & Persistent storage version number\\\hline
	1-7 & Reserved & Reserved for additional header data\\\hline\hline
	
	8 & HW Revision & Hardware Revision Code: Currently supported are 0x1 for NC1-1B\\\hline
	9-10 & Serial Number & Serial number of the Cone. \\\hline
	11-27 & Reserved & Reserved for future use. \\\hline
	28-31 & CRC & CRC Checksum for the hardware part.\\\hline\hline
	
	32-33 & Cone ID & ID of the cone used for lightmode settings.\\\hline
	34-35 & Reserved & Reserved for future use. \\\hline
	36-39 & Fallback Lightmode & The Lightmode that is turned on after start\\\hline
	40-41 & Status Refresh & Status Refresh period for ADC and status frame in ms. \\\hline
	42-59 & Reserved & Reserved for future use. \\\hline
	60-63 & CRC & CRC Checksum for user settings part. \\\hline
\end{tabular}
\end{table}

The config storage can be accessed system wide using the external variable \texttt{config\_store}. Saving the complete config storage to the EEPROM is only possible through the command line interface. Via the WLAN interface, only the user settings part can be saved. 

\subsection{i2ceeprom}
This simple driver for the I2C EEPROM can be used to write and read from the EEPROM. It uses the widely known \texttt{Wire} module from Arduino. If saving a block to the EEPROM, the whole block is first read and checked. Only if the new data differs from the old one, it is overridden. Otherwise, the data remains unchanged to increase the lifetime of the EEPROM chip. 

\subsection{credentials}
The credentials file is a smal file containing some sensitive data, namely the WLAN SSID, WLAN Key, OTA password, and OTA port. Only the template \texttt{\_credentials.txt} is checked into GIT, while the original file is excluded from GIT. This file must be renamed to \texttt{credentials.h} and filled with correct values. 

\subsection{color}
The color module is solely used to convert the received \qty{8}{\bit} code combined with the requested \qty{4}{\bit} brightness into the three \qty{8}{\bit} \ac{PWM} values. 
The conversion is done in a way, that the highest component (eg. red) equals the requested brightness. The other two color components are scaled accordingly. 

\subsection{led}
The \texttt{led.cpp} controls the \acp{LED} directly. The \texttt{led\_show} method takes an array of color components, that are written to the WS2812 \acp{LED}. The helper function \texttt{led\_clear} can be used to turn off all \acp{LED}. In addition the blue on-board \ac{LED} of the ESP-12 module can be blinked. This is realised using busy wait. Accordingly, this code is not realtime capable and should be used with care. 

The \texttt{led\_show\_status} is triggered, whenever the Hall sensor is set. It shows the temperature using the color of the top \acp{LED}. The 20 lower side \acp{LED} are used to show the current battery voltage level. 

\subsection{lightmodes}
This module is central for the function of the cone. It contains the definition of all light modes. The lightmode function is called by the \texttt{lightmode\_step} method. It takes the current time, the \texttt{lightmode} struct and the \texttt{ledstate} as arguments. It is called every \texttt{LED\_UPDATE\_INTERVAL} $= \qty{20}{\milli\s}$. The individual lightmode function is then required to keep track of its own state. For this purpose, the function gets the current time in milliseconds. The individual lightmodes are described in table \ref{tab_lightmode}. 

\subsection{ota}
The \texttt{ota} class is a wrapper for the \texttt{AndroidOTA} module. Only the \texttt{ota\_setup} and \texttt{ota\_loop} functions are used during operation. Everything else is used for debugging. 

The setup method sets the hostname to \texttt{Night-cone-XXXXXX} where the serial number from the flash is used in place of the "X". In addition, the password and the port are set. 

\subsection{sync}
The sync module is used to synchronise the time on the cone to a common carrier time. The server defines the main time, onto which all cones synchronize. A \qty{32}{\bit} time stamp representing the milliseconds since an arbitrary zero time is used by the server. This allows for a permanent operation for $\approx$ 50 days until a wraparound occurs. The sync module also directly implements the phase shift defined in the light mode. This simplifies the implementation of the light modes itself. The synchronizer is currently a very simple unfiltered \ac{PLL}. 

The \texttt{sync\_loop} function returns true whenever the \ac{LED} update interval is expired. It returns the current time in milliseconds as an argument. 

\subsection{wifi}
The \texttt{WIFI} module handles all communication between the server and the cone. The communication protocol is described in section \ref{sec_communication}. The communication ports are fixed. They can not be changed using the user config to reduce the risk of unreachable cones. 

\subsection{main}
The \texttt{main} file contains the two main functions. The \texttt{setup} method prepares everything for operation. The subsequent \texttt{loop} method is called permanently and executes all worker functions and also incorporates the dimming functionality (currently not active). 

\subsection{Programmer}
\label{programmer_software}

A small python script is used to program the ESP-12 and set the hardware part of the \texttt{config\_store} in one go. The suboptimal design using the FT234XD (See \ref{Programmer_Hardware}) requires some additional steps. 

A wrapper for the original \texttt{esptool.py} and the \texttt{pyftdi} library is used. This wrapper performs two actions. First, it overrides the \texttt{set\_dtr} with one, that uses the \texttt{CBUS0} pin instead of a (non-existing) nativ dtr signal. As a second operations, it replaces the serial interface in the ESP-Tool with the \texttt{serial\_ext} extension of the \texttt{pyftdi} library.

The \texttt{NC\_programmer.py} script is used to call the esptool and set the parameters. 

The script accepts all parameters of the native \texttt{esptool.py} and in addition the following arguments: 
\begin{itemize}
	\item First Positional argument: Path to the \texttt{esptool.py}
	\item \texttt{-s,--set\_EEPROM\_config}: This argument allows to set the hardware revision and the serial number. It takes two positional arguments \texttt{[Serial-number Hardware-revision]}.	Both can be decimal or hexadecimal. 
\end{itemize}

The \texttt{esptool.py} must be cloned to use it in the way, we use it. In the example call, it is cloned into the same folder as the night-cones repository. 

The example call below sets the serial number to \texttt{138} and the hardware revision to \texttt{0x2}. It flashes the ESP-12 module using the binary file from \texttt{.pio/build/nodemcuv2/firmware.bin}:
\begin{verbatim}
	NC_programmer.py -s 138 0x2 "../../../esptool/esptool.py" --chip esp8266 \
	--port "ftdi://ftdi:ft-x:0:1/1" --baud 115200 write_flash 0x0 \
	.pio\build\nodemcuv2\firmware.bin
\end{verbatim}

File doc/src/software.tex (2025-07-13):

\section{Software}
The software chapter describes all the code that runs on the computer, with which the operator controls all nightcones in the local network. This computer is denoted as \textit{Server}.  The software consists of various functional blocks that are summarized in the first subchapter. Each module is then explained in detail in the following subchapters. 
\subsection{Concept}
The software will be split into multiple modules, which should be able to be developed stand-alone. The modules are shortly described in this section. \\

There is one part that will be used in multiple modules. The map allowing to position the cones and show the states and allow to interact with the cones shall be the same for all modules. \\

All cones are uniquely identified using the serial number. This allows to include a cone into a network without any configuration on the device itself. The cone is then assigned an ID through the network interface. This ID is then used to set a color scheme for a cone. The system is designed, such that the ID \num{0} is the standard ID for all cones. An arbitrary number of cones is allowed to have the same ID. One can for example give all cones which are mounted on blue cones the ID 1 and all mounted on a yellow one ID 2. This would then allow the control these two sets independent. 

\subsubsection{Logger}
The logger module is responsible to handle all messages generated by the other modules and create log files and user messages accordingly. 

\textbf{Functions:}
\begin{itemize}
	\item Create long term log files for all relevant cones data (eg. Battery level, \ac{RSSI} etc)
	\item Store relevant Warnings, Errors and Failures with configurable level in a local log file. 
\end{itemize}

\textbf{Input:}
\begin{itemize}
	\item Log messages 
\end{itemize}

\textbf{Output:}
\begin{itemize}
	\item Log messanges to \ac{GUI}
	\item Log file
\end{itemize}

\subsubsection{Host-Network Interface}
The Host-Network Interface is responsible for everything that runs on the network interface. It handles all the communication to and from the cones. 

\textbf{Functions:}
\begin{itemize}
	\item List all available networks
	\item List all available Cones in a specific network
	\item Turn of a single cone or all cones in the network
	\item Stream data to cones
	\item List all cones information
	\item Set specific settings on cone
\end{itemize}

\textbf{Input:}

\begin{itemize}
	\item All data from network
	\item Current state from cones
	\item Current demanded light state
	\item Demanded settings
\end{itemize}

\textbf{Output:}
\begin{itemize}
	\item Received cone data
	\item Log messages
	\item Data transfer from and to the cones
\end{itemize}

\subsubsection{Network Manager}
The Network Manager is a simple \ac{GUI} used to interface with the Host-Network Interface. It allows to alter settings of the cones, perform \ac{OTA} updates and observe the current state of the cones. 

\textbf{Functions: }

\begin{itemize}
	\item Show all cones in a network
	\item Select a network
	\item Change settings of cones in network
	\item Activate/deactivate cones
	\item Software update
	\item Show current data of the cones
	\item Identify cones
	\item Show cones on air image or on map / custom map
	\item Draw on Map or air image
	\item Override current cone state
\end{itemize}

\textbf{Input:}

\begin{itemize}
	\item Available scenarios
	\item Current data
	\item interface to Host-Network-Interface
\end{itemize}

\textbf{Output:}
\begin{itemize}
	\item \ac{GUI}
\end{itemize}

\subsubsection{Scenario Designer/Manager}
The scenario Designer/Manager is used to design and apply  scenarios to all cones. The idea behind this module is on one side to create a project (eg. Skidpad) with various scenarios. Each scenario can be a single state or a time/manually stepped sequence of steps (eg. start: All dark, green animation, All green, yellow cones yellow, blue cones blue). Afterwards it should be possible to easy use these prepared scenarios. This could be done in a second view and should use keyboard shortcuts. 

\textbf{Functions: }
\begin{itemize}
	\item Play back static or dynamic scenario
	\item Prepare/design scenarios
	\item save/load scenarios
\end{itemize}

\textbf{Input:}
\begin{itemize}
	\item User Input
\end{itemize}

\textbf{Output:}
\begin{itemize}
	\item Scenarios to directly use inside project
	\item Saved scenarios
\end{itemize}

\subsubsection{Simulator}
the simulator shall be a drop in replacement to the Host-Network-Interface. It therefore shall not simulate the communication itself. It can be used to test the other modules, when no 100 Cones are available. It should behave the same as the host network interface and should be able to be selected as a possible network in the Network Manager. \\
The simulator shall also give the possibility to change the values of the cones (eg. Activate the Hall sensor, Change battery level etc).

\textbf{Functions: }
\begin{itemize}
	\item Show current light state of a cone on a map. 
	\item Move cones on the map/background
	\item Activate hall sensor
	\item Change \ac{SoC}
	\item Change \ac{RSSI}
\end{itemize}

\textbf{Input:}
\begin{itemize}
	\item Interface to Network Manager
	\item User inputs via \ac{GUI}
\end{itemize}

\textbf{Output:}

\begin{itemize}
	\item Visualisation
\end{itemize}

\subsection{Communication Protocol}
\label{sec_communication}
The proprietary communication protocol is based on \ac{UDP}. It uses simple messages without any checksum.  The different frame types have a fixed or variable length. In any case a single \ac{UDP} packet is used for a single message. All frame types share the same header. The frame types are defined below.
\subsubsection{Header}
The header contains simple information to classify the frame. It includes a millisecond time stamp (4 byte) used for synchronisation, an increasing Frame number and a version. The frame number must only be increased for data frames. It can be set to zero for all other frame types.
\begin{table}[h!]
	\centering
	\begin{zebratabular}{ccll}
		\rowcolor{gray}
		Byte & Size   & Name        & Description\\
		0    & \qty{1}{\byte} & Version		& \qty{4}{\bit} for major and \qty{4}{\bit} of minor revision\\
		1    & \qty{1}{\byte} & Frame Type  & Frame type as described in Table \ref{tab_frame_type}\\
		2    & \qty{1}{\byte} & Frame Number & strictly increasing counter to detect missing packages\\
		3    & \qty{1}{\byte} & Reserved	& Reserved for future use\\
		4-7  & \qty{4}{\byte} & Timestamp	& time stamp (milliseconds since arbitrary zero time)\\
	\end{zebratabular}
	\caption{Frame Header Definition}
	\label{tab_frame_header}
\end{table}

\begin{table}[h!]
	\centering
	\begin{zebratabular}{ccll}
		\rowcolor{gray}
		ID & Direction & Name		 & Definition \\
		0x00 & S->C & Data Frame       & Data Frame with current color data.\\
		0x01 & S->C &	Config Frame     & Config Frame for setting various parameters on the cone.\\
		0x02 & S->C & Settings Request & Request for all settings of a cone.\\
		0x03 & S->C & Status Request   & Request for short status of a cone.\\		
		
		&\\
		0x80 & C->S & Status Frame   & Status report from cone to server.\\
		0x81 & C->S & Settings Frame & All settings stored on the cone.\\		
		
	\end{zebratabular}
	\caption{Frame Type List}
	\label{tab_frame_type}
\end{table}

\subsubsection{0x00: Data Frame}
The data frame is used to send the new data to a set of cones. It is sent to the networks broadcast address. The cones then pick the data according to their ID. The frame must be at least \qty{12}{\byte} long, but can extend up to \qty{1.5}{\kilo\byte} without fragmentation. Larger packets could be fragmented. 
\begin{table}[h!]
	\centering
	\begin{zebratabular}{ccll}
		\rowcolor{gray}
		Byte & Size   		   & Name        	& Description\\
		0-7 & \qty{8}{\byte} & Header			& Header according to definition\\
		     &				   & Cone ID 0 Data	& \\		     
		8   & \qty{1}{\byte}  & Color      	& Color as described in Figure \ref{fig_color_scheme}\\
		9   & \qty{4}{\bit}   & Brightness 	& Brightness [\qtyrange[range-phrase=\textendash]{0}{100}{\percent}]\\
		9   & \qty{4}{\bit}   & Lightmode 		& Light mode as described in Table \ref{tab_lightmode}\\
		10   & \qty{1}{\byte}  & Repetition Time& Repetition time for periodic color scheme $\times\qty{100}{\ms}$\\
		11   & \qty{1}{\byte}  & Phase Shift 	& Phase shift in $[0 - 2\pi]$\\
		&				   &			& \\
		12-15&	\qty{4}{\byte} 			   & Cone ID 1 Data	& Formatted according to Cone ID 0 Data\\		
		16-19&	\qty{4}{\byte} 			   & Cone ID 2 Data	& Formatted according to Cone ID 0 Data\\		
		...  & &&\\     
	\end{zebratabular}
	\caption{Data Frame Definition}
	\label{tab_data_frame}
\end{table}

\textbf{Lightmodes}

The currently implemented lightmodes are described in table \ref{tab_lightmode}.  

\begin{table}[h!]
	\centering
	\begin{zebratabular}{cp{50pt}p{170pt}p{30pt}p{60pt}p{80pt}}
		\rowcolor{gray}
		ID & Mode  	& Description & 
		Color & 
		Brightness & 
		Repetition \newline time  \\
	    
	    0 & Continuous & Continuous light & Yes & Yes & Don’t care\\
	
		1 & Blinking & Blinking with duty cycle \qty{50}{\percent} & Yes & Yes & 
		Blinking time (\qtyrange[range-phrase=\textendash]{0.1}{25.5}{\s})\\
		
		2 & Blinking short & Blinking with duty cycle \qty{25}{\percent} & Yes & Yes & 
		Blinking time (\qtyrange[range-phrase=\textendash]{0.1}{25.5}{\second})\\
		
		3 & Blinking long & Blinking with duty cycle \qty{75}{\percent} & Yes & Yes & 
		Blinking time (\qtyrange[range-phrase=\textendash]{0.1}{25.5}{\second})\\
		
		4 & Circulating & Circulating light.  \newline Bottom LEDs only. \newline 3 at a time. & Yes & Yes & 
        Rotation time step (\qtyrange[range-phrase=\textendash]{0.1}{25.5}{\second})\\
		
		5 & Circulating smooth & Circulating light. \newline Bottom LEDs only. 
        \newline 1 at full $b$ brightness\newline 2 with $0.66\cdot b$ brightness 
        \newline 2 with $0.33\cdot b$ brightness & Yes & Brightness $b$ of middle LED & 
        Rotation time step(\qtyrange[range-phrase=\textendash]{0.1}{25.5}{\second})\\
		
		6 & Fade & Single color, brightness fades between zero to maximum value & Yes & Maximum brightness &
        Fade cycle time (\qtyrange[range-phrase=\textendash]{0.1}{25.5}{\second})\\
		
		7 & Rainbow fade & Continuous light, color fades in rainbow colors & Don’t care & Yes &
        Fade cycle time (\qtyrange[range-phrase=\textendash]{0.1}{25.5}{\second})\\
		
		8 & Rainbow circle & Each LED around the circle has one of the rainbow colors.
        \newline Colors rotate with given frequency & Don’t care & Yes & 
        Rotation time (\qtyrange[range-phrase=\textendash]{0.1}{25.5}{\second})\\
		
		9 & Identification & Blinking with duty cycle \qty{50}{\percent}\newline
		\qty{2}{\Hz} with a significant color on full brightness. 
        \newline LED nearest to sensor (number 3) continuously on & Don’t care & Don’t care & Don’t care\\
		
		10 - 15 & reserved\\
	\end{zebratabular}
	\caption{Data Frame Definition}
	\label{tab_lightmode}
\end{table}

\textbf{Color}

As 256 colors are sufficient for this application, the color is transmitted as \qty{8}{\bit} number instead of a \qty{8}{bit} triplet. This saves some bandwidth. The color scheme is developed in a way, that it repeats from 0 to 223. The range between 224 to 255 is used to swipe to white, also allowing the use of white color. The green change from 128 to 192 is stretched, to allow for more intermediate steps from yellow to red. 
There are some color nuances, that are not able to be encoded. This includes the transient to white from any color to white.   

\begin{figure}[h!]
	\centering
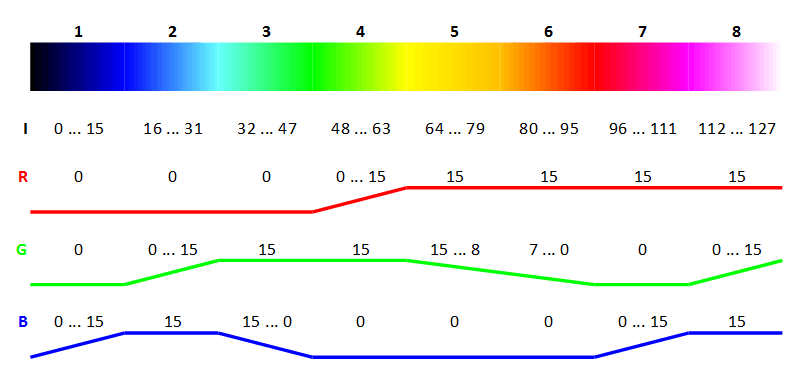
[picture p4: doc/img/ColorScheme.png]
	
	\caption{Color distribution in $\qty{8}{\bit}$ according to the following scheme. 
	}
	\label{fig_color_scheme}
\end{figure}

\textbf{Brightness}

The brightness is sent as \qty{4}{\bit} value. The highest color component value is chosen and scaled with the brightness value to be relative to \qty{8}{\bit}. If two colors have the same highest brightness, the first is chosen.

For all other color components, their fragment of the brightest color is calculated and then scaled with the brightness value to be relative to \qty{8}{\bit}.
\FloatBarrier

\subsubsection{0x01: Config Frame}
There is one Frame, that can be used, to set various settings on the cone. This could be the ID or a command (eg. to turn the cone off). The IDs are described in details in table \ref{tab_config_IDs}. Multiple parameters can be set with a single frame. 
\begin{table}[h!]
	\centering
	\begin{zebratabular}{ccll}
		\rowcolor{gray}
		Byte & Size   		   & Name        	& Description\\
		0-7 & \qty{8}{\byte} & Header			& Header according to definition\\
		& & &\\	     
		8-11& \qty{4}{\byte}  & Parameter ID   & ID of parameter to be changed\\
		12-15& \qty{4}{\byte}  & Value  		& Value to be set\\	
		.. & \qty{8}{\byte} & Next Parameter & Multiple parameters can be set by writing further parameters.\\
	\end{zebratabular}
	\caption{Config Frame Definition}
	\label{tab_config_frame}
\end{table}

\begin{table}[h!]
	\centering
	\begin{zebratabular}{cll}
		\rowcolor{gray}
		ID & Name        	& Description\\
		0 & HW Revision & Hardware revision encoded as \qty{8}{\bit} hex number. \\
		1 & Software Rev	& Software Revision \qty{1}{\byte} for major, \qty{1}{\byte} for minor revision\\	
		2 & Serial Number & Unique serial number of the cone (\qty{16}{\bit})\\
		3 & Cone ID & Light mode ID of the cone  (\qty{16}{\bit})\\
		4 & Fallback Lightmode & Default Light mode used at startup (\qty{4}{\byte})\\
		5 & Turn Off & Write a 1 to restart the ESP, write any other number to turn the cone off.\\
		6 & Bat Volage & Battery voltage in \si{\milli\volt}.\\
		7 & Temperature & Temperature of the cone in \si{\celsius}.\\
		8 & Status Period & Period of the Status frame in milliseconds (\qty{16}{\bit}). \\
		9 & Debug 1 & \qty{32}{\bit} value for debug purposes.\\
		10 & Debug 2 & \qty{32}{\bit} value for debug purposes.\\
		11 & Debug 3 & \qty{32}{\bit} value for debug purposes.\\
		12 & Debug 4 & \qty{32}{\bit} value for debug purposes.\\
		13 & Save \acs{EEPROM} & Store the user configuration to the \ac{EEPROM}.\\
		14 & Frame Error & Error counter for damaged/invalid received frames. \\
		15 & Frame order & Error counter for frame order.\\
        16 & Ident Mode & Set to 1 to enable Ident mode, write 0 to deactivate.\\
        17 & Turnoff Voltage & If set to a value  $\neq 0$, the cone turns off at this voltage.\\
        18 & IP Address & Static IP Address if set to a value other than 0\\
        19 & Gateway & Static IP Gateway. \\
        20 & Subnet Mask & \\
        21 & Rst Info 1 & Reset Info according to reset struct\\
        22 & Rst Info 2 & Reset Info according to reset struct\\
        23 & Rst Info 3 & Reset Info according to reset struct\\
        24 & Rst Info 4 & Reset Info according to reset struct\\
        25 & Rst Info 5 & Reset Info according to reset struct\\
        26 & Rst Info 6 & Reset Info according to reset struct\\
        27 & Rst Info 7 & Reset Info according to reset struct\\
        
		\end{zebratabular}
	\caption{Config Frame IDs}
	\label{tab_config_IDs}
\end{table}

\FloatBarrier

\subsubsection{0x02/0x03:Settings/Status Request}
The Request Frame is used to request the Settings or status frame from a specific cone. When sent to the Broadcast address, all cones shall send a response. This frame does not contain any data. 
\begin{table}[h!]
\centering
\begin{zebratabular}{ccll}
	\rowcolor{gray}
	Byte & Size   		   & Name        	& Description\\
	0-7 & \qty{8}{\byte} & Header			& Header according to definition (Type 2 or 3)\\
\end{zebratabular}
\caption{Request Frame Definition}
\label{tab_request_frame}
\end{table}
\\

\subsubsection{0x80: Status Frame}
The status frame is periodically requested by the server and contains current status data as well as relevant Identification values. 
\begin{table}[h!]
	\centering
	\begin{zebratabular}{ccll}
		\rowcolor{gray}
		Byte & Size   		   & Name        	& Description\\
		0-7 & \qty{8}{\byte} & Header			& Header according to definition\\
		& & &\\	     
		8-9 & \qty{2}{\byte}  & ID  			& ID of the cone\\
		10  & \qty{1}{\byte}  & \ac{SoC}		& State of Charge scaled [\qtyrange[range-phrase=\textendash]{0}{100}{\percent}]\\
		11  & \qty{1}{\byte}  & \ac{RSSI} 	& \ac{RSSI} value scaled according to ESP\\	
		12	& \qty{1}{\byte}  & Temperature  &  Temperature in \si{\celsius}.\\
		13   & \qty{1}{\byte}  & Hall Sensor	& Hall switch state [0/1]\\	
	\end{zebratabular}
	\caption{Status Frame Definition}
	\label{tab_settings_frame}
\end{table}

\subsubsection{0x81: Settings Frame}
Due to low amount of configuration data of the cone, only all data can be requested. Each parameter uses \qty{8}{\byte}. The complete parameter list sent in this frame is described in table \ref{tab_config_IDs}.
\begin{table}[h!]
	\centering
	\begin{zebratabular}{ccll}
		\rowcolor{gray}
		Byte & Size   		   & Name        	& Description\\
		0-7 & \qty{8}{\byte} & Header			& Header according to definition\\
		& & &\\     
		8-11& \qty{4}{\byte}  & Parameter ID   & ID of parameter to be changed\\
		12-15& \qty{4}{\byte}  & Value  		& Value to be set\\	
		...&&&\\
	\end{zebratabular}
	\caption{Settings Frame Definition}
	\label{tab_settings_frame}
\end{table}

\FloatBarrier
\subsection{Logger}
The python module \texttt{Logging} is used for logging in the whole application. This makes it extremely simple to log any events. The logger is configured in the top module \texttt{LoggingManager}. The configuration itself is done using a \ac{JSON} formatted file. This file should be used by the user to tailor the logging behaviour if necessary. 
\subsubsection{HowTo Logging}
At least every large submodule as described above should have its own logger. If more loggers are needed, they can be created. Table  \ref{tab_logger} collects all loggers, that are created in the application. 
\begin{table}[h!]
	\centering
	\begin{zebratabular}{ll}
		\rowcolor{gray}
		Module &
		Logger Name \\
		server-Network-Interface & NetworkInterface  \\
	\end{zebratabular}
	\caption{Logger Names}
	\label{tab_logger}
\end{table}

The logger can be created using \pythoninline{logger = logging.getLogger("your-best-logger-name")}. Creating messages is then pretty straight forward: 
\begin{python}
logger.debug("Debug message")
logger.info("Info message")
logger.warning("Warning message")
logger.error("Error message")
logger.critical("Critical message")
\end{python}

\subsubsection{LoggingManager}
The \texttt{LoggingManager} class together with the Handlers is used to filter and categorize the logger messages. 
\todo{Write Code and document it here}

\subsection{Server-Network-Interface}

This module is used to interface to any available network. It must be instantiated in the application. This allows to have multiple interfaces in parallel.

\subsubsection{Command line Interface}
The Module features a command line Interace, which can be used by running the python file \texttt{NetworkInterface.py}. The available options and corresponding functions can primarily be looked up using the \texttt{-h/--help} switch. Commands that need more explanation are explained hereinafter.  

\subsubsection{Defining the used network}
The module uses the \texttt{ifaddr} module for discovery of all available network interfaces. The returned list of type \texttt{ifaddr.Adapter} can be used to select the correct adapter. The adapter is selected by specifying the name and the used IP address. If the \ac{IP} address is not available, the first \ac{IP} address is used. 

\subsubsection{Network Operation}
The module has multiple threads, that can be launched to operate on the network interface. 

\textbf{Discovery Thread}\\
The discovery thread is used to collect data about all available cones. This includes only the periodic data (battery voltage, \ac{RSSI} etc). The data itself is buffered on the module, to allow access to it permanently. Each received message is pushed to the logger with level 

\textbf{Streaming Thread}\\
The streaming thread is used to send the current light state to all cones through a multicast message. This is done in the background. 
\todo{Define interface to get current light state from other application modules}

\subsubsection{\acs{UDP} Access}
One Thread is simply responsible to receive the packets.

\subsection{Network Manager}

\subsection{Scenario Designer}

\subsection{Simulator}

\subsection{Licensing}

As this software is intended to be made open source in near or far future, the license thematic is an important topic. Therefore all python dependencies are listed in the following table. 

\begin{table}[h!]
	\centering
	\begin{zebratabular}{llll}
		\rowcolor{gray}
		Module &
		pip install name & 
		License & url \\
		\texttt{ifaddr} & \texttt{ifaddr}  & MIT &  \url{https://github.com/pydron/ifaddr} \\
	\end{zebratabular}
	\caption{Python Dependencies} 	
	\label{tab_py_dependencies}
\end{table}

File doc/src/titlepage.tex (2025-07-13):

\begin{titlepage}

    \vspace{4mm}

    \begin{center}
        %\missingfigure{Title image}
        %\addcontentsline{lof}{figure}{Title image}
        
    \end{center} 

    %\vspace{2mm}

    \begin{center}
        \rule{\textwidth}{2pt}
    \end{center}

    \vspace{2mm}

    \begin{center}
      \huge{\textbf{NightCones}}\\
      \LARGE{\textbf{Open Source Cone illumination Devices}}\\
        \vspace{4mm}
        \Large{Technical documentation}
    \end{center}
    
    %\vspace{2mm}

    \begin{center}
        \rule{\textwidth}{2pt}
    \end{center}

    \vspace{4mm}

    \begin{center}
        Authors:\\
        \large{\makeatletter \@author \makeatother}\\
        \vspace{4mm}
    \end{center}

    \vspace{3mm}

    \begin{center}
        Schwyz, \today
    \end{center}

\end{titlepage}
\clearpage

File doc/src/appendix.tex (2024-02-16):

\section{Appendix}
\subsection{Requirements}\label{app:requirements}
\clearpage

\subsection{Schematics}
\label{app:schematic}
\includepdf[pages=-, offset=0cm -2.5cm, frame=true, angle=0, fitpaper]{\schfile}

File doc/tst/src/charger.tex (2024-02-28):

\begin{formtable}
 \formTitle{Charger}
 \formNoteV{Apply \qty{6}{\volt} to CHG\_A CHG\_B}{GND}
 \formHeader
 \formMeasure{Voltage on +5V\_CHG}          {\qtyrange{5.0}{6.0}{\volt}}
 \formMeasure{Charging current}             {\qty{0.0}{\ampere}}
 \formNoteV{Connect Battery simulator or load and power supply to battery pads and set power supply to \qty{3.7}{\V}}{GND}
 \formMeasure{Voltage on +5V\_CHG}          {\qtyrange{4.5}{5.0}{\volt}}
 \formMeasure{Charging current}             {$\qtyrange{650}{780}{\milli\ampere}$}
 \formMeasure{Temperature of U1 *}          {\qty{80}{\celsius}}
 \formNoteV{Disconnect CHG\_A, apply \qty{6}{\volt} to CHG\_B}{GND}
 \formMeasure{Charging current}             {$\qtyrange{650}{780}{\milli\ampere}$}
 \formNoteV{Disconnect CHG\_B, apply \qty{6}{\volt} to CHG\_C}{GND}
 \formMeasure{Charging current}             {$\qtyrange{650}{780}{\milli\ampere}$}
 \formNote{Disconnect charging supply, keep circuit in deep sleep. }{}
 \formMeasure{Quiescent Current}             {$\qtyrange{20}{30}{\micro\ampere}$} 
\end{formtable}

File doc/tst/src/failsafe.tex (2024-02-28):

\begin{formtable}
 \formTitle{Failsafe}
 \formNoteV{Apply \qty{4}{\volt} to +VBAT}{GND}
 \formHeader
 \formMeasure{FS\_PULSE (TP13) high time}       {\qtyrange{580}{1600}{\nano\second}}
 \formMeasure{FS\_PULSE (TP13) low time}        {\qtyrange{220}{420}{\nano\second}}
 \formMeasure{FS\_DATA (TP14) pulse count}      {512}
 \formNoteV{When the controller is not programmed yet, apply a pulse to DATA\_5V}{GND}
 \formMeasure{FS\_EDGE (U4, pin 3)}             {Low pulse on every rising edge of DATA\_5V}
 \formMeasure{FS\_ACT/ (TP11)}                  {Low}
 \formMeasure{DATA\_FAILSAFE (TP12)}            {Valid Neopixel signal}
 \formNoteV{Short DATA\_5V to GND (short Q3)}{GND}
 \formMeasure{FS\_ACT/ (TP11)}                  {Low after a delay of \qty{100}{\milli\second}}
 \formMeasure{DATA\_FAILSAFE (TP12)}            {Valid Neopixel signal}
\end{formtable}

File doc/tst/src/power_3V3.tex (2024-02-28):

\begin{formtable}
 \formTitle{Power supply \qty{3.3}{\volt}}
 \formNoteV{Apply \qty{4}{\volt} to +VBAT. Apply \qty{6}{\V} to charging connectors. Place magnet next to hall sensor. }{GND}
 \formHeader
 \formMeasure{Voltage on +3V3}                  {\qtyrange{3.2}{3.4}{\volt}}
 \formMeasure{Switching frequency}              {\qtyrange{1.9}{2.1}{\mega\hertz}}
 \formNoteV{Apply a load current of \qty{0.3}{\ampere}}{GND}
 \formMeasure{Temperature of U29 *}             {<\qty{80}{\celsius}}
 \formMeasure{Temperature of L2 *}              {<\qty{80}{\celsius}}
\end{formtable}

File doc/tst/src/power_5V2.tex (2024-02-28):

\begin{formtable}
 \formTitle{Power supply \qty{5.2}{\volt}}
 \formNoteV{Apply \qty{4}{\volt} to +VBAT. Apply \qty{6}{\V} to charging connectors. Place magnet next to hall sensor. }{GND}
 \formHeader
 \formMeasure{Voltage on +5V2}                  {\qtyrange{5.1}{5.3}{\volt}}
 \formMeasure{Switching frequency}              {\qtyrange{0.9}{1.1}{\mega\hertz}}
 \formNoteV{Apply a load current of \qty{1.0}{\ampere}}{GND}
 \formMeasure{Temperature of U28 *}             {<\qty{80}{\celsius}}
 \formMeasure{Temperature of L1 *}              {<\qty{80}{\celsius}}
\end{formtable}

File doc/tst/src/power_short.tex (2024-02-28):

\begin{formtable}
 \formTitle{Power supply short circuit}
 \formNoteR{Check supply nets for short circuits}
 \formHeader
 \formMeasure{Resistance +VBAT $\to$ -VBAT}             {OL}
 \formMeasure{Resistance +VBAT $\to$ GND}               {OL}
 \formMeasure{Resistance CHG\_A $\to$ GND}              {>\qty{10}{\kilo\ohm}}
 \formMeasure{Resistance CHG\_B $\to$ GND}              {>\qty{10}{\kilo\ohm}}
 \formMeasure{Resistance CHG\_C $\to$ GND}              {>\qty{10}{\kilo\ohm}}
 \formMeasure{Resistance +5V5 $\to$ GND}                {>\qty{1}{\kilo\ohm}}
 \formMeasure{Resistance +3V3 $\to$ GND}                {>\qty{10}{\kilo\ohm}}
\end{formtable}

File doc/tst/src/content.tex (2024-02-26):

\input{src/title}

%%Note: every form item needs a unique name

\newpage
\begin{Form}[]
\centering
\input{src/assembly}
\input{src/power_short}
\input{src/power_5V2}
\input{src/power_3V3}
\input{src/charger}
\input{src/failsafe}
\input{src/programming}
\end{Form}

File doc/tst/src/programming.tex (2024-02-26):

\begin{formtable}
	\formTitle{Programming}
	\formNote{Connect GPIO0 to GND and connect programming pins (GND, UART\_TX, UART\_RX)}{Restart or reset the ESP Module}
	\formHeader
	\formCheck{Controller can be programmed}
	\formNote{Disconnect GPIO0 from GND}{Restart or reset the ESP Module}
	\formCheck{New Firmware is programmed on the ESP Module}
\end{formtable}

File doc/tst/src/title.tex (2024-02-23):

\begin{Form}[]
\fontsize{25pt}{20}\selectfont Commissioning Protocol for PCB NC1-1AA: \TextField[name=Title, bordercolor = black, borderstyle = U]{}\\

Performed by: \TextField[name=Name, bordercolor = black, borderstyle = U]{}
\end{Form}

\vspace{6cm}

For the use of this document several points should be noted:

\begin{itemize}
\item Manufacturing/soldering steps are noted in \textcolor{green}{green}
\item It is expected for the steps to be done from top to bottom.
\item For measurements where polarity is relevant (including resistance measurements), the connection for the positive probe is noted first.
\item For the expected resistance values it was assumed that no current will flow into any semiconductors the actual values might be lower. Consider the test passed when the measured value seems reasonable.
\item All current values are only estimates. The measured value might differ substantially. Consider the test passed when the measured value is either below the expected value or can  be considered safe.
\item Tests where the description is marked with a asterisk (*) can be considered optional when time is critical.

\end{itemize}

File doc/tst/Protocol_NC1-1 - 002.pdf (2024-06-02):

NightCones | Commissioning protocol

# Commissioning Protocol for PCB NC1-1AA: 002

# Performed by: Andreas & Daniel

For the use of this document several points should be noted:

- Manufacturing/soldering steps are noted in green
- It is expected for the steps to be done from top to bottom.
- For measurements where polarity is relevant (including resistance measurements), the connection for the positive probe is noted first.
- For the expected resistance values it was assumed that no current will flow into any semiconductors the actual values might be lower. Consider the test passed when the measured value seems reasonable.
- All current values are only estimates. The measured value might differ substantially. Consider the test passed when the measured value is either below the expected value or can be considered safe.
- Tests where the description is marked with a asterisk (*) can be considered optional when time is critical.
February 24, 2024 | Andreas Horat Daniel Winz

Assembly
Description | Expected Value | Measured Value | Passed | Comments

Replace D6 with a red LED

Remove C55 and C58

Remove D11

Remove D14 and D15

Change R16 from 100K/0603 to 10K/0603

Change R19 from 270R/0603 to 100R/0603

perform optical check

Power supply short circuit Check supply nets for short circuits
⃝i Measure resistances expected to be OL at the highest range on the multimeter
Description | Expected Value | Measured Value | Passed | Comments
Resistance +VBAT → -VBAT | OL 3MOhm
Resistance +VBAT → GND | OL OL
Resistance CHG_A → GND | >10 kΩ 35kOhm
Resistance CHG_B → GND | >10 kΩ 34kOhm
Resistance CHG_C → GND | >10 kΩ 34kOhm
Resistance +5V5 → GND | >1 kΩ 40kOhm
Resistance +3V3 → GND | >10 kΩ 38kOhm

Power supply 5.2 V
Apply 4 V to +VBAT. Apply 6 V to charging connectors. Place magnet next to hall sensor.
⃝i Measure voltages with reference to GND.
Description | Expected Value | Measured Value | Passed | Comments
Voltage on +5V2 | 5.1 V . . . 5.3 V 5.18V
Switching frequency | 0.9 MHz Skipped . . . 1.1 MHz

Apply a load current of 1.0 A
⃝i Measure voltages with reference to GND.
Temperature of U28 * | <80 ◦C 60°C
Temperature of L1 * | <80 ◦C <60°C

Power supply 3.3 V
Apply 4 V to +VBAT. Apply 6 V to charging connectors. Place magnet next to hall sensor.
⃝i Measure voltages with reference to GND.
Description | Expected Value | Measured Value | Passed | Comments
Voltage on +3V3 | 3.2 V . . . 3.4 V 3.34V
Switching frequency | 1.9 MHz Skipped . . . 2.1 MHz

Apply a load current of 0.3 A
⃝i Measure voltages with reference to GND.
Temperature of U29 * | <80 ◦C No Full Load possible -> Problem with BMS
Temperature of L2 * | <80 ◦C

Charger
Apply 6 V to CHG_A CHG_B
⃝i Measure voltages with reference to GND.
Description | Expected Value | Measured Value | Passed | Comments
Voltage on +5V_CHG | 5.0 V . . . 6.0 V 5.21V
Charging current | 0.0 A 0.04A
Connect Battery simulator or load and power supply to battery pads and set power supply to 3.7 V ⃝i Measure voltages with reference to GND.
Voltage on +5V_CHG | 5.5 V . . . 5.0 V 4.73V
Charging current | 650 mA to 695mA 780 mA
Temperature of U1 * | 80 ◦C 60°C
Disconnect CHG_A, apply 6 V to CHG_B
⃝i Measure voltages with reference to GND.
Charging current | 650 mA | to 695mA
| 780 mA
Disconnect CHG_B, apply 6 V to CHG_C
⃝i Measure voltages with reference to GND.
Charging current | 650 mA | to 695mA
| 780 mA
Disconnect charging supply, keep circuit in deep sleep.
Quiescent Current | 20 µA to 30 µA 12.8uA

Failsafe
Apply 4 V to +VBAT
⃝i Measure voltages with reference to GND.
Description | Expected Value | Measured Value | Passed | Comments
FS_PULSE (TP13) high time | 580 ns 1240ns . . . 1600 ns
FS_PULSE (TP13) low time | 220 ns . . . 420 ns 380ns
FS_DATA (TP14) pulse count | 512 Needs Redesign
When the controller is not programmed yet, apply a pulse to DATA_5V ⃝i Measure voltages with reference to GND.
FS_EDGE (U4, pin 3) | Low pulse on ev- skip ery rising edge of DATA_5V
FS_ACT/ (TP11) | Low skip
DATA_FAILSAFE (TP12) | Valid Neopixel skipskip signal

Short DATA_5V to GND (short Q3)
⃝i Measure voltages with reference to GND.
FS_ACT/ (TP11) | Low after a de- skip lay of 100 ms
DATA_FAILSAFE (TP12) | Valid Neopixel signal

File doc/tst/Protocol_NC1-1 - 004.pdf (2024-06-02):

NightCones | Commissioning protocol

# Commissioning Protocol for PCB NC1-1AA: 004

# Performed by: Andreas & Daniel

For the use of this document several points should be noted:

- Manufacturing/soldering steps are noted in green
- It is expected for the steps to be done from top to bottom.
- For measurements where polarity is relevant (including resistance measurements), the connection for the positive probe is noted first.
- For the expected resistance values it was assumed that no current will flow into any semiconductors the actual values might be lower. Consider the test passed when the measured value seems reasonable.
- All current values are only estimates. The measured value might differ substantially. Consider the test passed when the measured value is either below the expected value or can be considered safe.
- Tests where the description is marked with a asterisk (*) can be considered optional when time is critical.
February 24, 2024 | Andreas Horat Daniel Winz

Assembly
Description | Expected Value | Measured Value | Passed | Comments

Replace D6 with a red LED

Remove C55 and C58

Remove D11

Remove D14 and D15

Change R16 from 100K/0603 to 10K/0603

Change R19 from 270R/0603 to 100R/0603

perform optical check

Power supply short circuit Check supply nets for short circuits
⃝i Measure resistances expected to be OL at the highest range on the multimeter
Description | Expected Value | Measured Value | Passed | Comments
Resistance +VBAT → -VBAT | OL 5.6MOhm
Resistance +VBAT → GND | OL 1MOhm
Resistance CHG_A → GND | >10 kΩ 21kOhm
Resistance CHG_B → GND | >10 kΩ 21kOhm
Resistance CHG_C → GND | >10 kΩ 21kOhm
Resistance +5V5 → GND | >1 kΩ 40KOhm
Resistance +3V3 → GND | >10 kΩ 40kOhm

Power supply 5.2 V
Apply 4 V to +VBAT. Apply 6 V to charging connectors. Place magnet next to hall sensor.
⃝i Measure voltages with reference to GND.
Description | Expected Value | Measured Value | Passed | Comments
Voltage on +5V2 | 5.1 V . . . 5.3 V 5.14V
Switching frequency | 0.9 MHz . . . 1.1 MHz

Apply a load current of 1.0 A
⃝i Measure voltages with reference to GND.
Temperature of U28 * | <80 ◦C
Temperature of L1 * | <80 ◦C

Power supply 3.3 V
Apply 4 V to +VBAT. Apply 6 V to charging connectors. Place magnet next to hall sensor.
⃝i Measure voltages with reference to GND.
Description | Expected Value | Measured Value | Passed | Comments
Voltage on +3V3 | 3.2 V . . . 3.4 V 3.31
Switching frequency | 1.9 MHz . . . 2.1 MHz

Apply a load current of 0.3 A
⃝i Measure voltages with reference to GND.
Temperature of U29 * | <80 ◦C
Temperature of L2 * | <80 ◦C

Charger
Apply 6 V to CHG_A CHG_B
⃝i Measure voltages with reference to GND.
Description | Expected Value | Measured Value | Passed | Comments
Voltage on +5V_CHG | 5.0 V . . . 6.0 V 5.42V
Charging current | 0.0 A
Connect Battery simulator or load and power supply to battery pads and set power supply to 3.7 V ⃝i Measure voltages with reference to GND.
Voltage on +5V_CHG | 5.5 V . . . 5.0 V 4.76V
Charging current | 650 mA to 678mA 780 mA
Temperature of U1 * | 80 ◦C
Disconnect CHG_A, apply 6 V to CHG_B
⃝i Measure voltages with reference to GND.
Charging current | 650 mA | to 675mA
| 780 mA
Disconnect CHG_B, apply 6 V to CHG_C
⃝i Measure voltages with reference to GND.
Charging current | 650 mA | to 676mA
| 780 mA
Disconnect charging supply, keep circuit in deep sleep.
Quiescent Current | 20 µA to 30 µA 9.9mA @3.7V

Failsafe
Apply 4 V to +VBAT
⃝i Measure voltages with reference to GND.
Description | Expected Value | Measured Value | Passed | Comments
FS_PULSE (TP13) high time | 580 ns 1253ns . . . 1600 ns
FS_PULSE (TP13) low time | 220 ns . . . 420 ns 437ns
FS_DATA (TP14) pulse count | 512
When the controller is not programmed yet, apply a pulse to DATA_5V ⃝i Measure voltages with reference to GND.
FS_EDGE (U4, pin 3) | Low pulse on ev-ery rising edge of DATA_5V
FS_ACT/ (TP11) | Low
DATA_FAILSAFE (TP12) | Valid Neopixel signal

Short DATA_5V to GND (short Q3)
⃝i Measure voltages with reference to GND.
FS_ACT/ (TP11) | Low after a de-lay of 100 ms
DATA_FAILSAFE (TP12) | Valid Neopixel signal

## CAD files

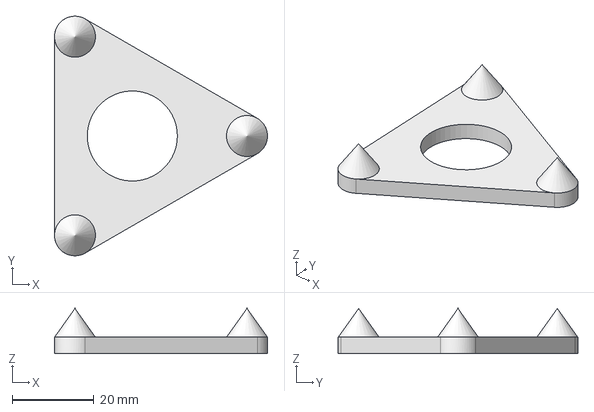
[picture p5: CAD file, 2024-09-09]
cad/NC1-1_Weight_Plate.FCStd
52.0 x 58.5 x 11.0 mm

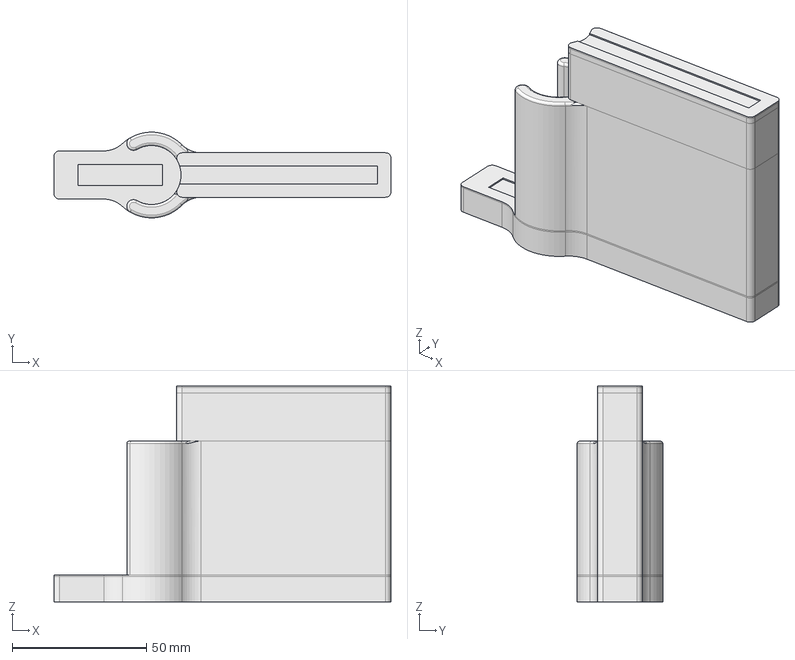
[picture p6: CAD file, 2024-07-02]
cad/cell_welding_jig_lower.FCStd
125.7 x 32.0 x 80.5 mm

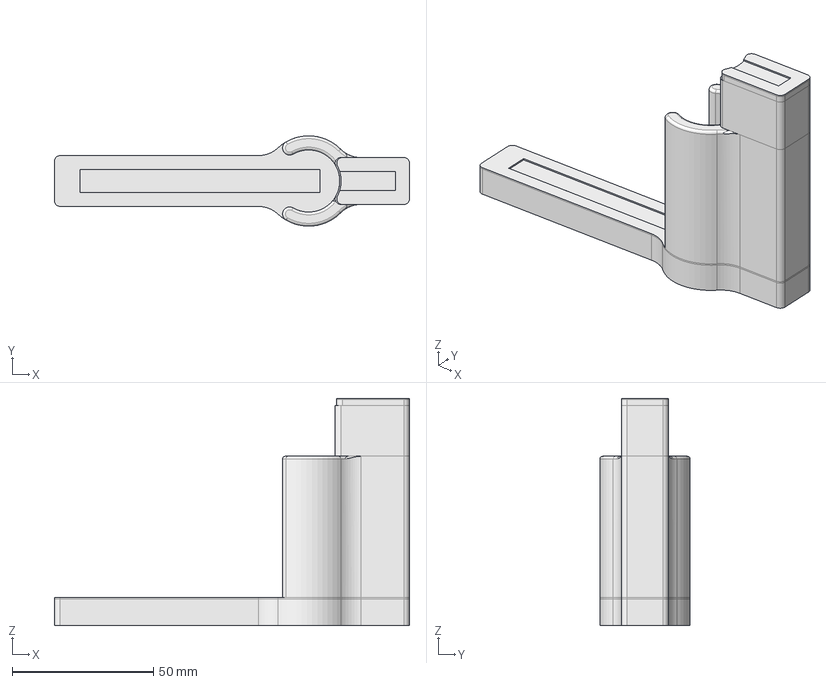
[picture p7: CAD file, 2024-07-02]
cad/cell_welding_jig_upper.FCStd
125.7 x 32.0 x 80.5 mm

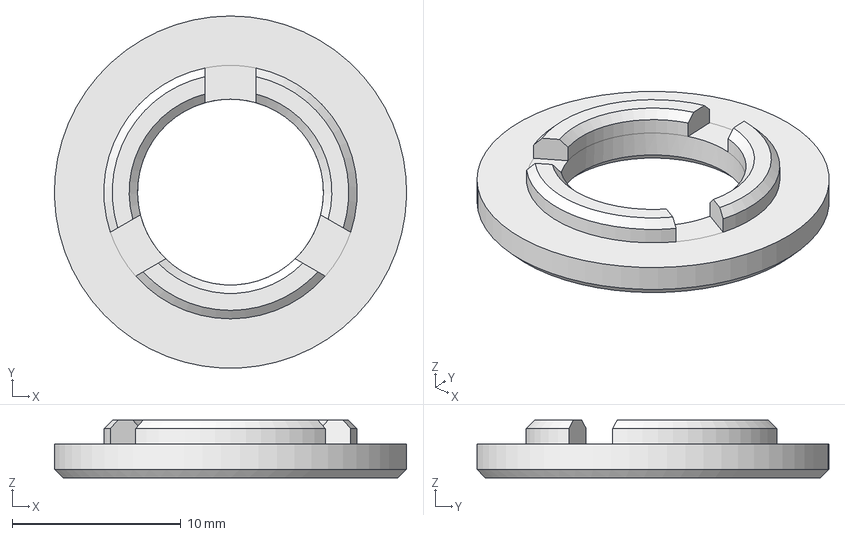
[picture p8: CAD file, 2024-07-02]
cad/cell_protection_ring.FCStd
20.8 x 20.8 x 3.41 mm

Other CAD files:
cad/Housing_NC1-3/Housing_Lower.ipt
cad/Housing_NC1-3/Housing_Upper.ipt
cad/night-cone_bottom_v3.prt
cad/night-cone_box.prt
cad/night-cone_contact-rail.prt
cad/night-cone_middle_v3.prt
cad/night-cone_pcb-spacer_v3.prt
cad/night-cone_plate_v3.prt
cad/night-cone_top_v2.prt
cad/night-cones_rail-mount.prt
cad/tuflock_m3x18.prt

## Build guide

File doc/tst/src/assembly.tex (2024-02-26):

\begin{formtable}
 \formTitle{Assembly}
 \formHeader
 \formWork{Replace D6 with a red LED}
 \formWork{Remove C55 and C58}
 \formWork{Remove D11}
 \formWork{Remove D14 and D15}
 \formWork{Change R16 from 100K/0603 to 10K/0603}
 \formWork{Change R19 from 270R/0603 to 100R/0603} 
 \formCheck{perform optical check}
\end{formtable}

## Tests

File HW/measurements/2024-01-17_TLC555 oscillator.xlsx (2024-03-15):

C | RA | RB | t_h | t_l | T
1e-09 | 1100 | 470 | 1737 | 740.5 | 2478
4.7e-10 | 1100 | 470 | 929.8 | 395.6 | 1325
4.7e-10 | 1100 | 390 | 920.8 | 378.6 | 1299
4.7e-10 | 1100 | 0 | 943.9 | 148.7 | 1093
4.7e-10 | 1100 | 220 | 857 | 281.8 | 1139
4.7e-10 | 1100 | 270 | 885.8 | 315.8 | 1202
4.7e-10 | 1500 | 270 | 1104 | 320 | 1424
4.7e-10 | 1500 | 1000 | 1315 | 641.7 | 1957
4.7e-10 | 1500 | 1500 | 1479 | 857.4 | 2336
4.7e-10 | 1500 | 1300 | 1406 | 768 | 2174
4.7e-10 | 1000 | 1300 | 1190 | 787.8 | 1977
4.7e-10 | 910 | 1300 | 1155 | 794.4 | 1949
4.7e-10 | 680 | 1300 | 1050 | 821 | 1871
470 | 680 | 1200 | 1004 | 767 | 1771
4.7e-10 | 750 | 1200 | 1053 | 776.3 | 1830
4.7e-10 | 820 | 1200 | 1070 | 762.1 | 1832
4.7e-10 | 910 | 1200 | 1130 | 771.2 | 1901
NC1-1AA - 007
4.7e-10 | 1500 | 100 | 1257 | 433 | 1691
2.2e-10 | 1500 | 100 | 771 | 410 | 1186

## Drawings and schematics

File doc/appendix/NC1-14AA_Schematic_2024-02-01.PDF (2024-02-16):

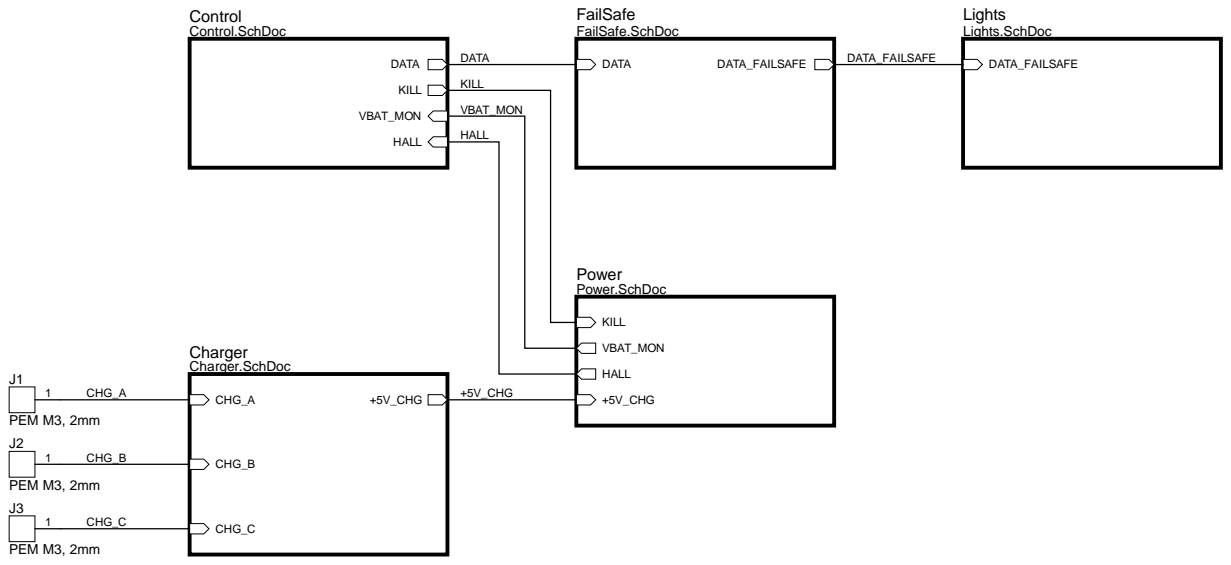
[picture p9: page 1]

2024-Feb-01
Schema: ahorat / daniwLayout: daniw

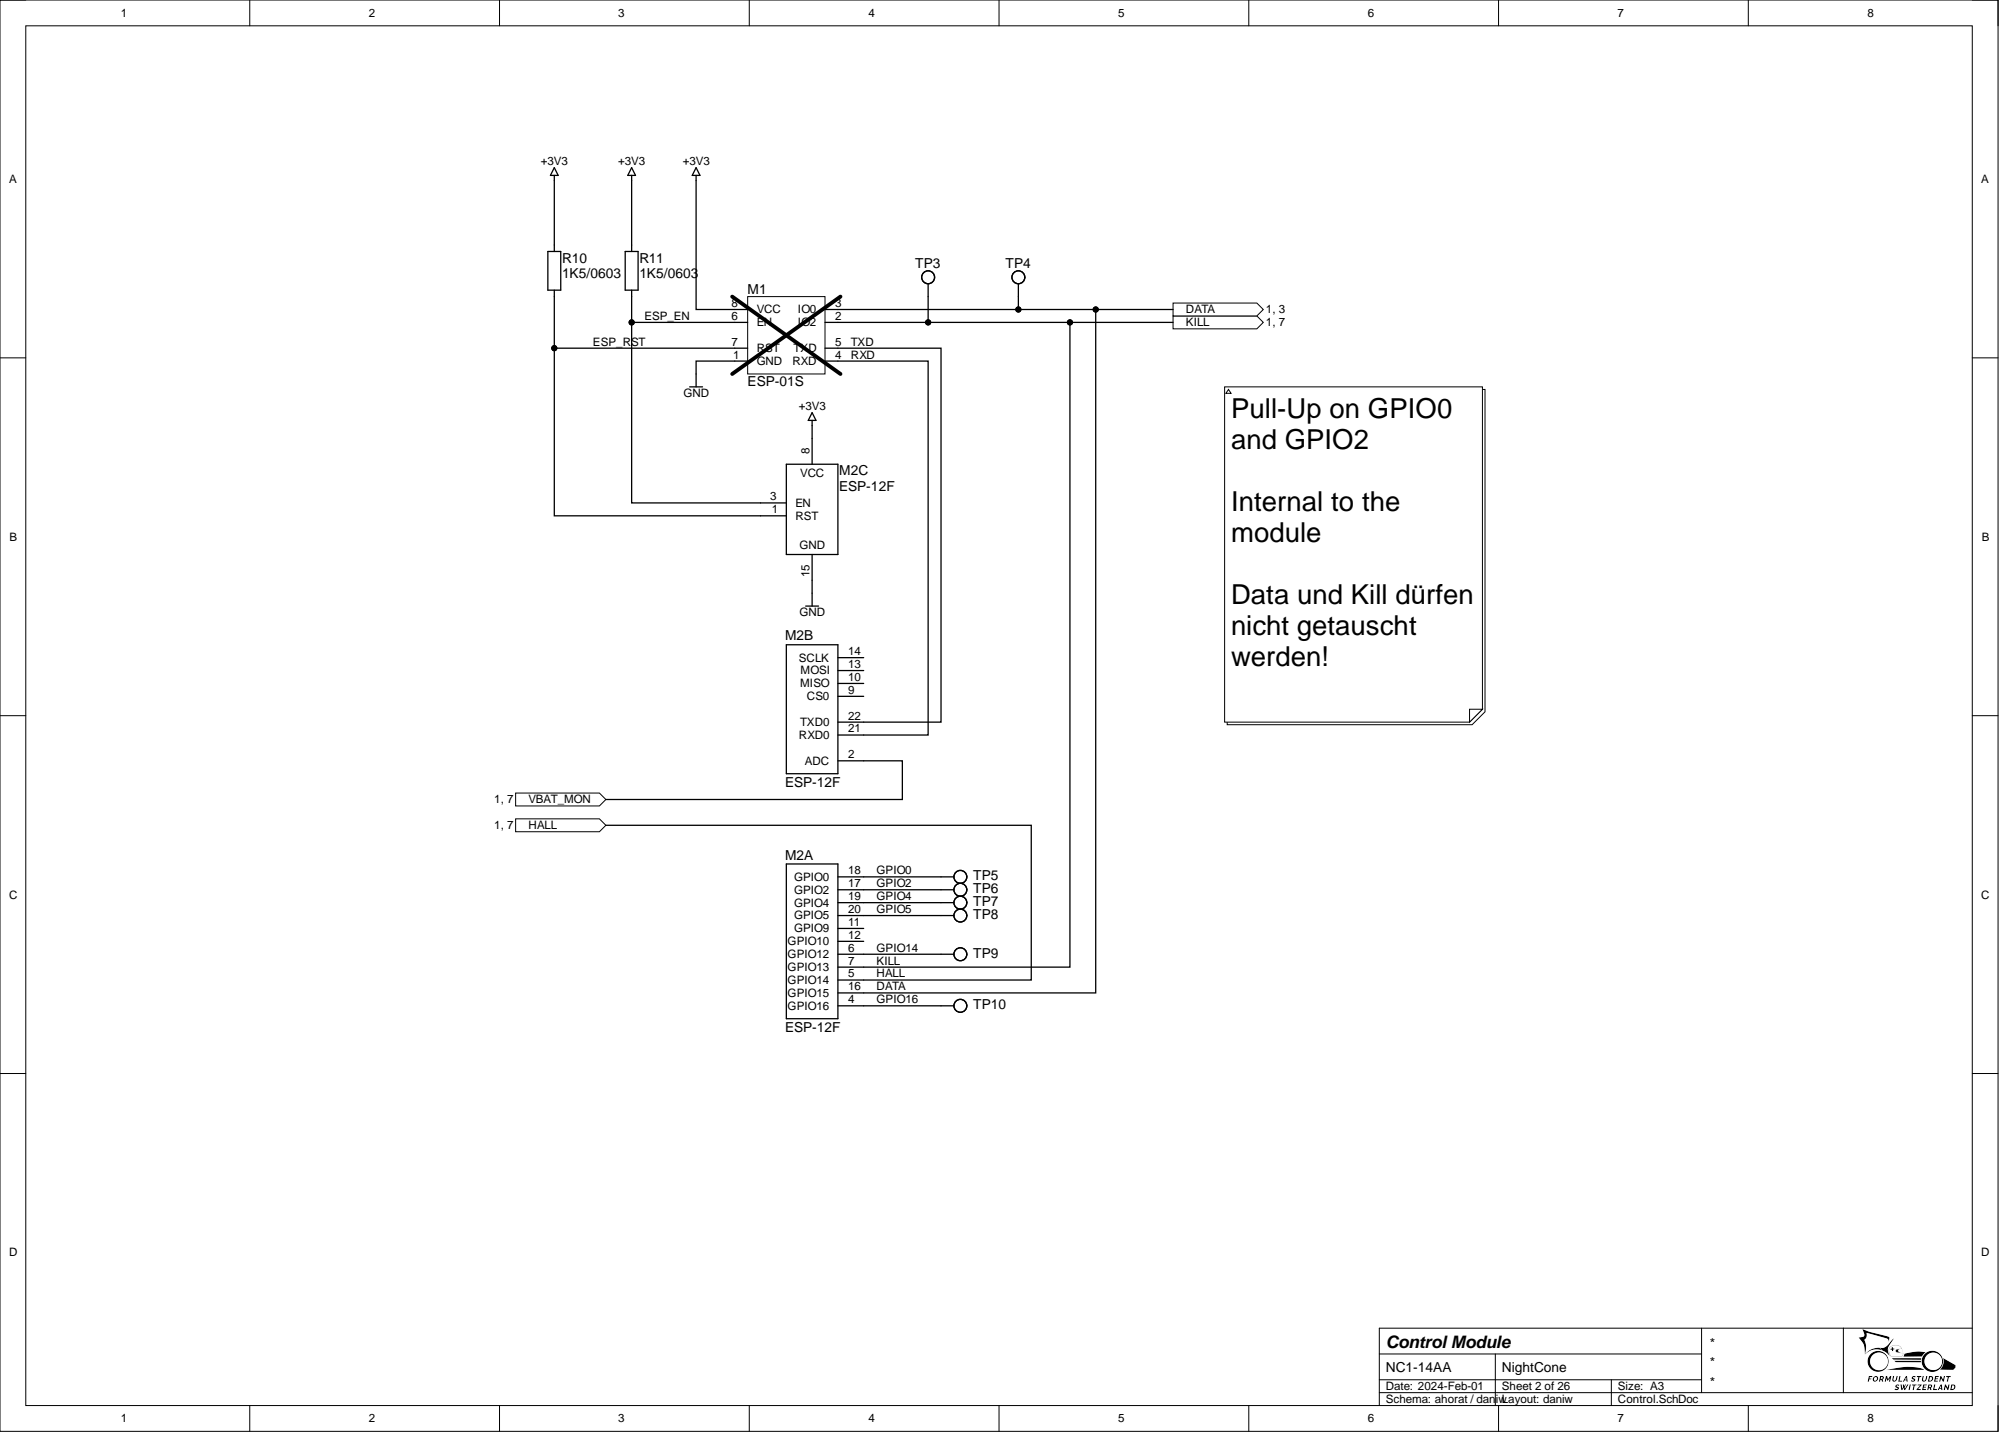
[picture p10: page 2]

Data und Kill dürfen
nicht getauscht
werden!

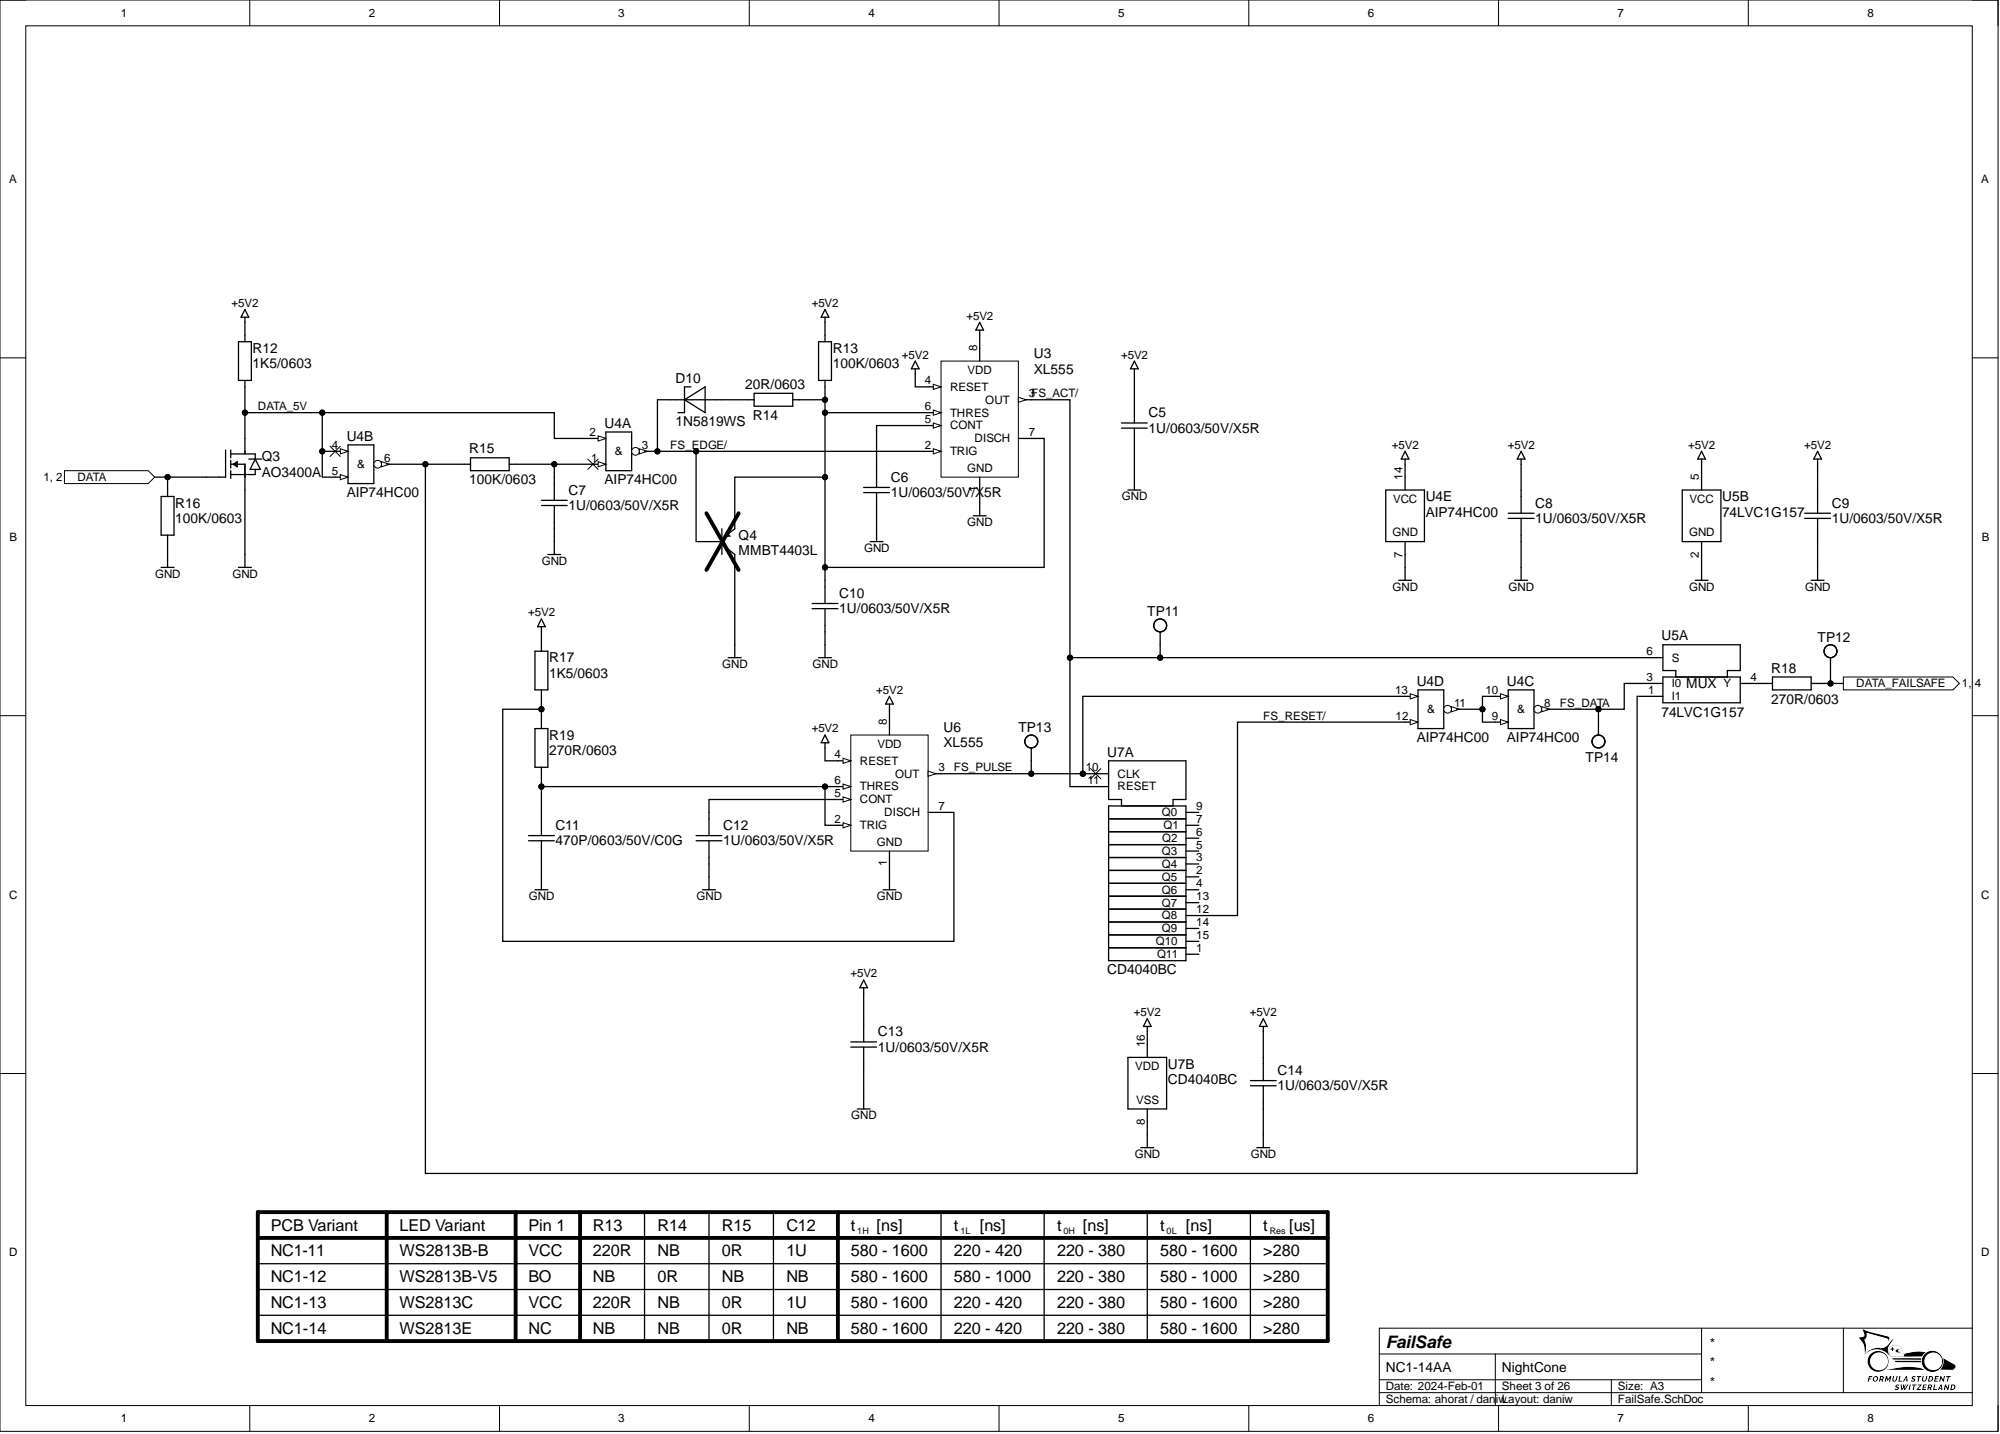
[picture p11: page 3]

8 FS_D ATA | 1

PCB Variant | LED Variant | Pin 1 | R13 | R14 | R15 | C12 | t [ns ] 1 H | t [ns ] 1 L | t [ns ] 0 H | t [ns ] 0 L | t Re [us ] s
N C1-1 1 | WS2813B-B | VC C | 220R NB | N B | 0RNB | 1UNB | 580 - 1600 | 220 - 420 | 220 - 380 | 580 - 1600 | >280
N C1-12 | WS2813B-V 5 | B O | | | | | 580 - 1600 | 580 - 1000 | 220 - 380 | 580 - 1000 | >280
N C1-13 | WS2813 C | VC C | 220R NB | 0RNBNB | 0R | 1UNB | 580 - 1600 | 220 - 420 | 220 - 380 | 580 - 1600 | >280

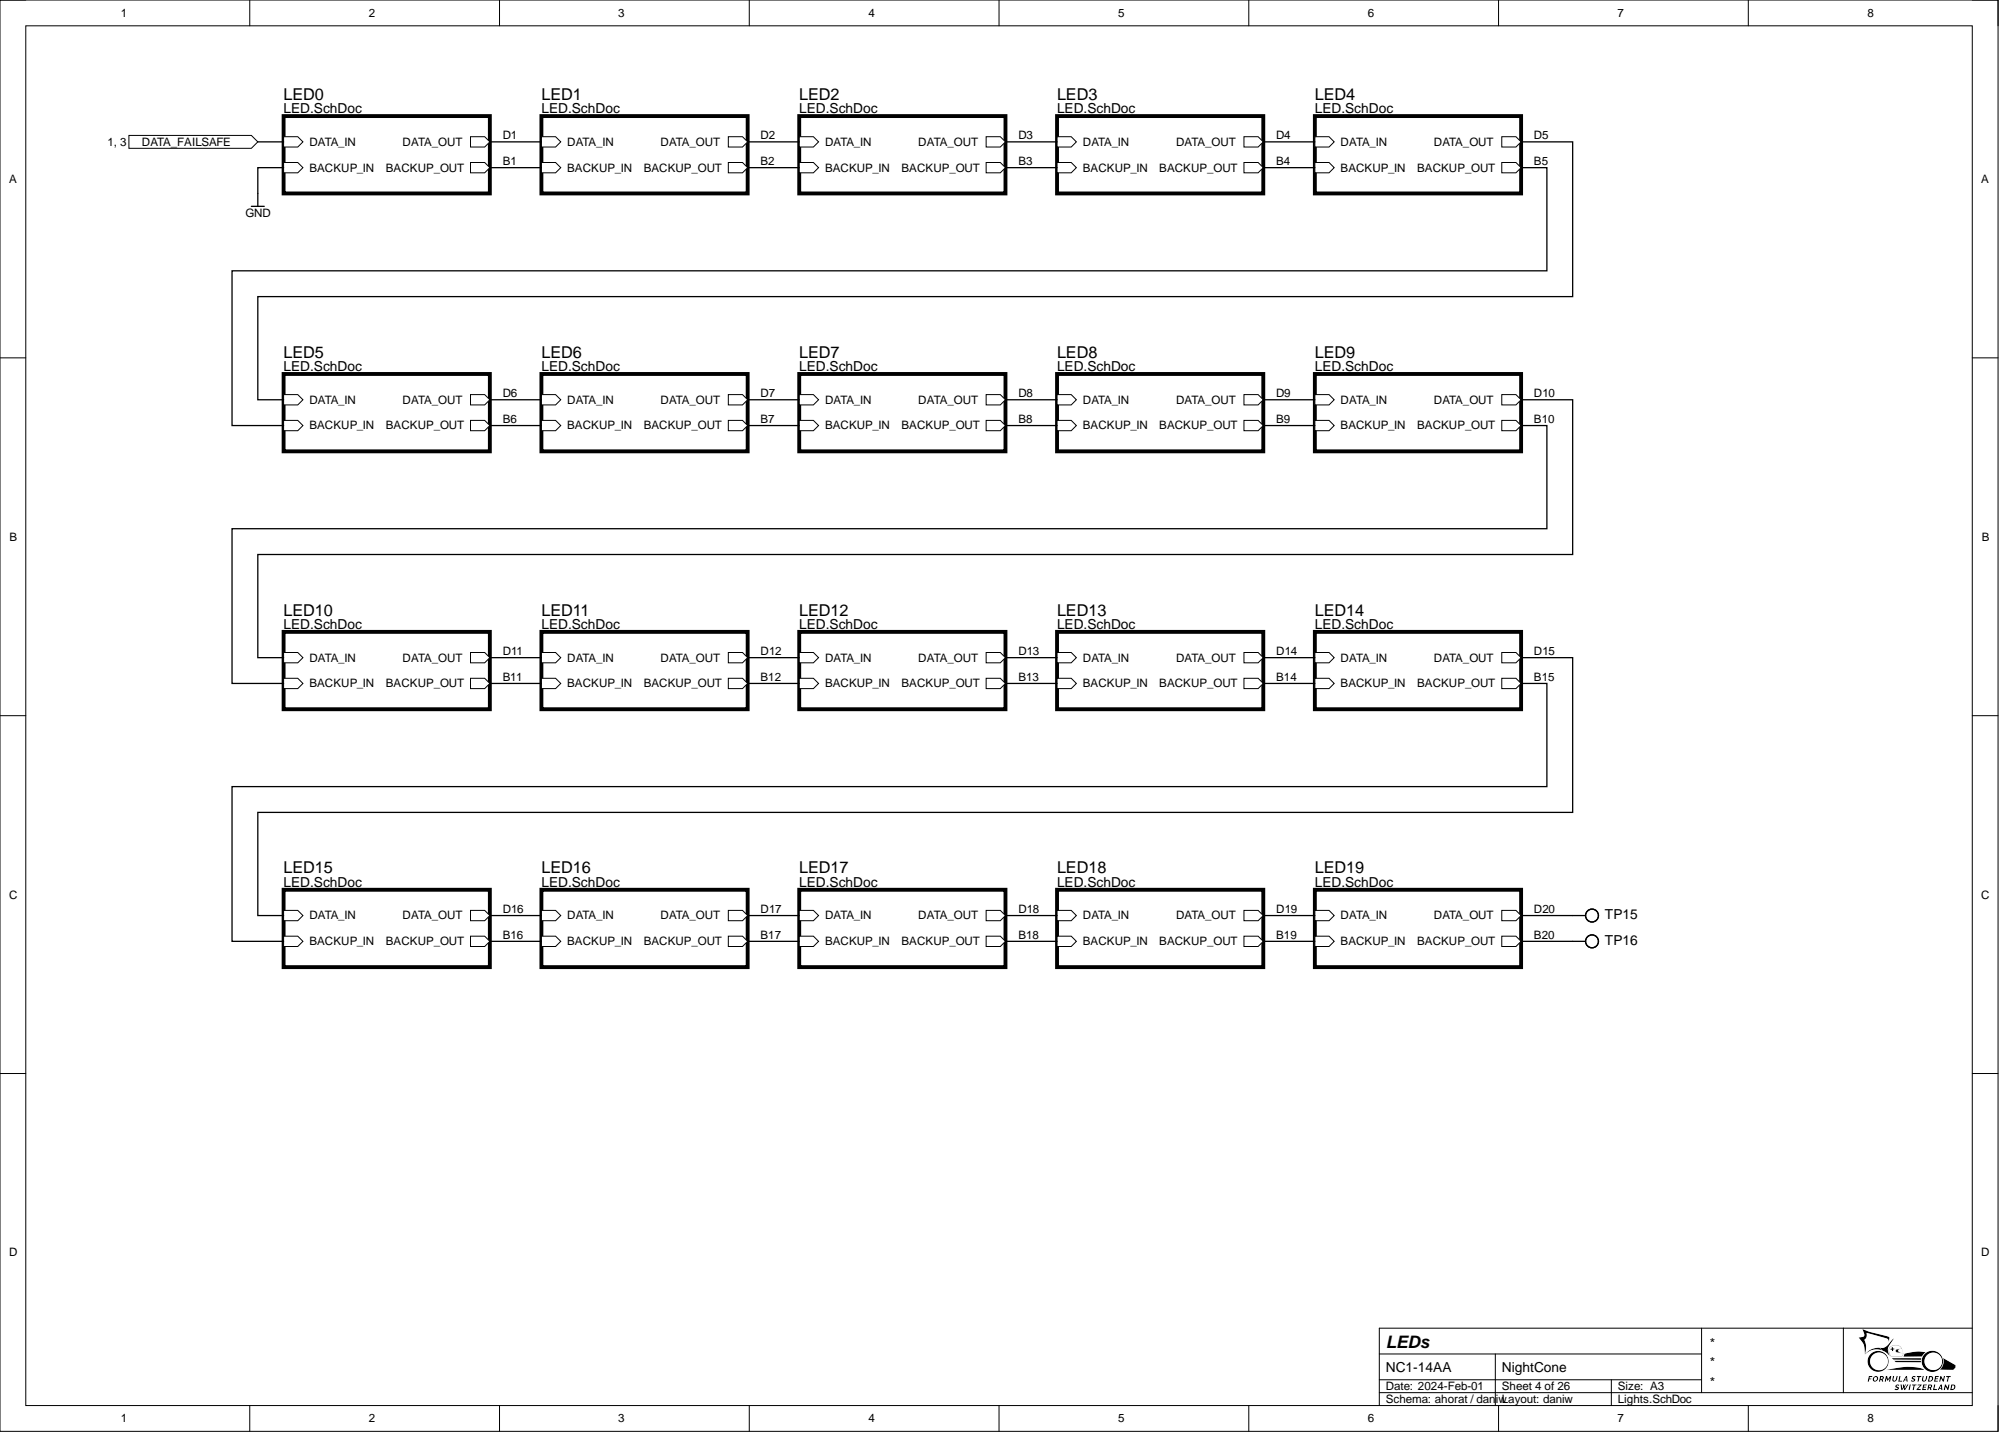
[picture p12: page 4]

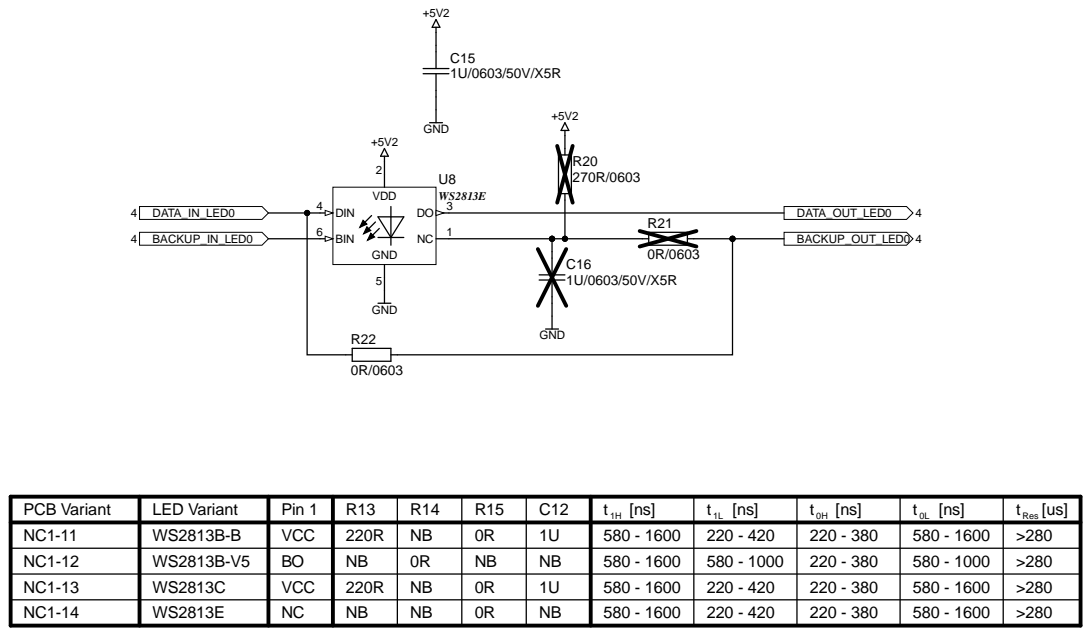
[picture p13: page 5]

PCB Variant | LED Variant | Pin 1 | R13 | R14 | R15 | C12 | t 1H | t 1L [ns] | t 0H [ns] | t 0L [ns] | t Res [ns] [us]
NC1-11 | WS2813B-B | VCC | 220R | NB | 0R | 1U | 580 - 1600 | 220 - 420 | 220 - 380 | 580 - 1600 | >280
NC1-12 | WS2813B-V5 | BO | NB | 0R | NB | NB | 580 - 1600 | 580 - 1000 | 220 - 380 | 580 - 1000 | >280
NC1-13 | WS2813C | VCC | 220R | NB | 0R | 1U | 580 - 1600 | 220 - 420 | 220 - 380 | 580 - 1600 | >280
NC1-14 | WS2813E | NC | NB | NB | 0R | NB | 580 - 1600 | 220 - 420 | 220 - 380 | 580 - 1600 | >280

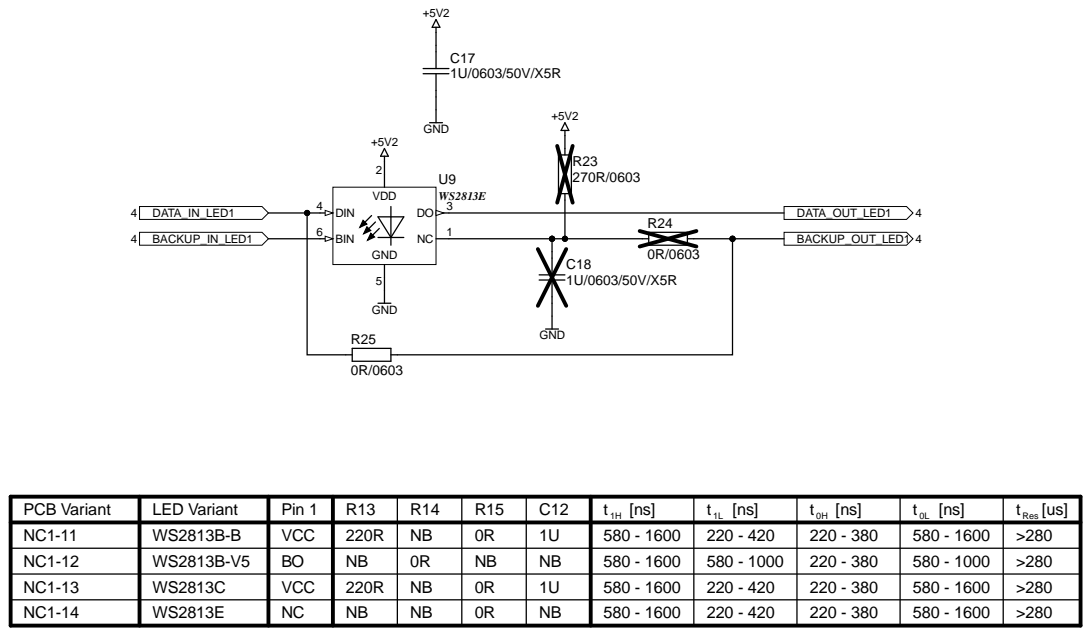
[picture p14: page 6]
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

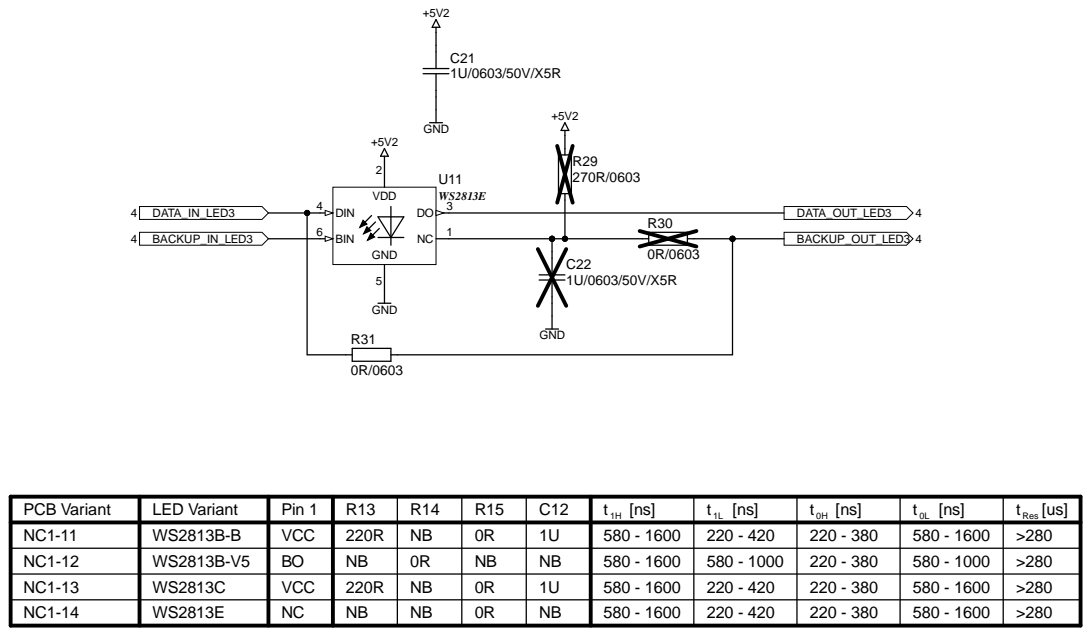
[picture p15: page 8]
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

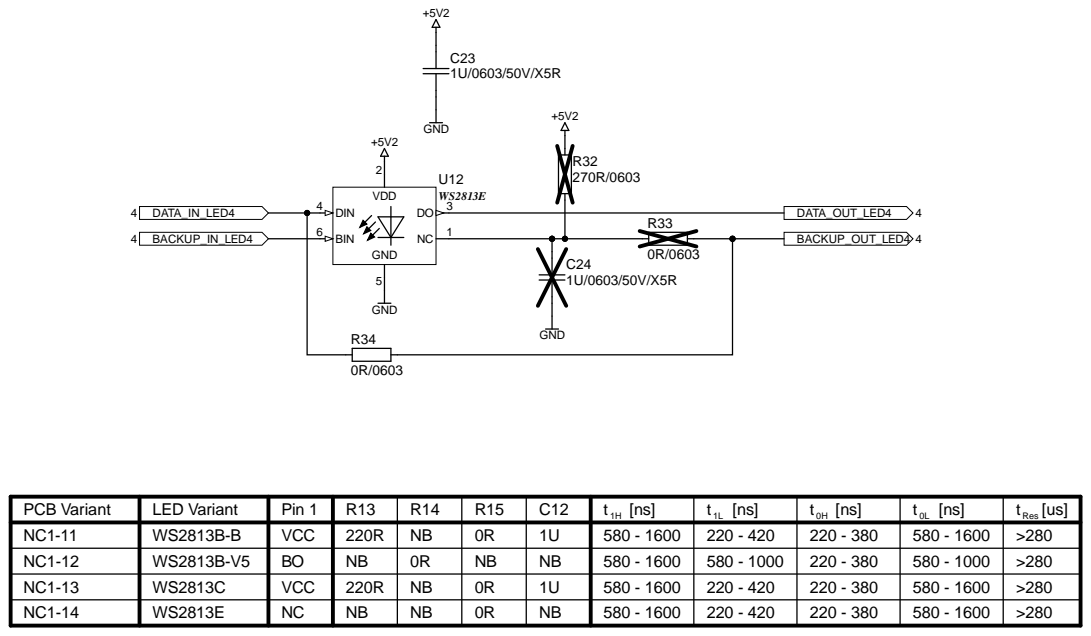
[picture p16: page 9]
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

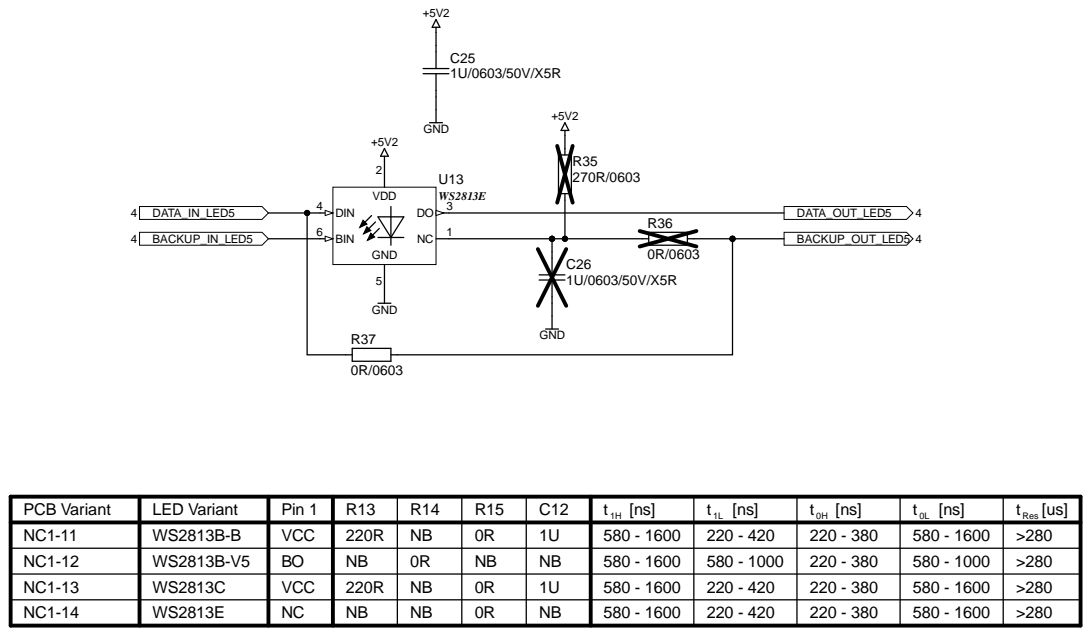
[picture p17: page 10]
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

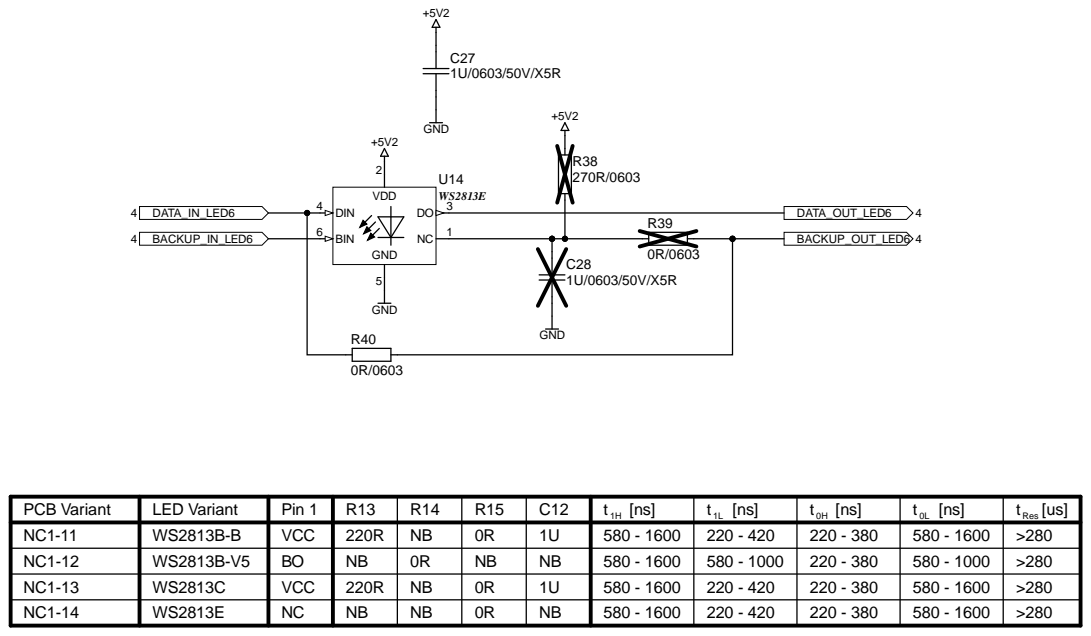
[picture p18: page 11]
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

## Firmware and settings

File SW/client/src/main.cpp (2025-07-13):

/*******************************************************************************/
/*
 * File: main.cpp
 * Author: Andreas Horat
 */
/*******************************************************************************/
/*
 * Main file for nightcones
 */
/*******************************************************************************/
#include "Arduino.h"
#include "HardwareSerial.h"
#include "adc.h"
#include "cli.h"
#include "color.h"
#include "config_store.h"
#include "hw_ctrl.h"
#include "led.h"
#include "lightmodes.h"
#include "sync.h"
#include "wifi.h"

#define BRIGHTNESS_DEFAULT 0x70



#define WIFI_DELAY_MS 100
#define WIFI_LOOPS    50

const long LED_UPDATE_INTERVAL = 25;  // initial interval at which to blink (milliseconds)

void setup() {
  // Setup Hardware
  Serial.begin(115200);
  //delay(2000);
  config_store_setup();
  hw_ctrl_setup(config_store.hardware_data.hardware_revision);
  adc_setup();
  sync_setup(LED_UPDATE_INTERVAL);

  // LED setup
  led_setup(config_store.hardware_data.hardware_revision);
  lightmode_setup();

  // Init LEDs with blue
  // In case the Default mode would turn off everything, we first need to
  // wake the failsafe by switching shortly to blue and then go to black.
  lightmode_switch(COLOR_BLUE, 0x20, 0);
  lightmode_step(0, led_state); // Is used to activate the lightmode
  led_show(led_state);

  //delay(500);
  wifi_setup();
  // Switch to default lightmode
  led_show(led_state);
  lightmode_switch(config_store.user_settings.fallback_color,
                   config_store.user_settings.fallback_lightmode,
                   config_store.user_settings.fallback_repetition_time);
  lightmode_step(0, led_state);
  led_show(led_state);
  cli_init();
}

void loop()
{

  wifi_loop();

  cli_loop();

  uint32_t currentMillis;
  if (sync_loop(&currentMillis))
  {

    lightmode_step(currentMillis, led_state);
    // ToDo Implement Dimming here. 
    /*if (adc_temp_deg < 20)
    {
      // lightmode_dim(BRIGHTNESS_DEFAULT);
    }
    else if (adc_temp_deg > 60)
    {
      //lightmode_dim(0x10);
    }
    else
    {
      //lightmode_dim((16 + ((60-adc_temp_deg) * )) & 0xF0);
    }*/

    if (hw_ctrl_get_hall_state())
    {
      led_show_status(adc_temp_deg, adc_volt_meas);
    }
    else
    {
      led_show(led_state);
    }
  }
  
  if(currentMillis % 1000==0){
    // Measure temperature and battery voltage
    adc_loop();
    // if the voltage measured is smaller than the turn off threshold, it is turned off. 
    if(config_store.user_settings.turn_off_voltage_mv > adc_volt_meas)
        hw_ctrl_turn_off();
  }
  
  if (config_store.user_settings.status_refresh_period_ms != 0 && (currentMillis % config_store.user_settings.status_refresh_period_ms == 0))
  { // Transmit the status frame
    wifi_status_transmit();
  }
}

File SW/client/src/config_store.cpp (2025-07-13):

#include "i2cEeprom.h"
#include "config_store.h"
#include "Arduino.h"
#include "Wire.h"
#include "HardwareSerial.h"
#include <EEPROM.h>
#define DEBUG

#define CONFIG_STORE_SDA_PIN 2
#define CONFIG_STORE_SCL_PIN 14

#define CONFIG_STORE_EEPROM_HEADER_BASE_ADDRESS 0
#define CONFIG_STORE_EEPROM_HEADER_SIZE 8
#define CONFIG_STORE_EEPROM_HARDWARE_DATA_BASE_ADDRESS 8
#define CONFIG_STORE_EEPROM_USER_SETTIGS_BASE_ADDRESS 32
#define CONFIG_STORE_EEPROM_SIZE 256
#define CONFIG_STORE_EEPROM_PAGE_SIZE 8
#define CONFIG_STORE_EEPROM_ADDRESS 0xA0

#define CONFIG_STORE_EEPROM_USED_SIZE (CONFIG_STORE_EEPROM_HEADER_SIZE + CONFIG_STORE_HARDWARE_DATA_SIZE + \
                                       4 + CONFIG_STORE_USER_SETTINGS_SIZE + 4)

config_store_t config_store;
TwoWire I2C;
bool externalEEprom;

/**
 * Configure Config store with defaults and load data from EEPROM.
 *
 */
void config_store_setup(void)
{
    I2C = TwoWire();
    I2C.begin(CONFIG_STORE_SDA_PIN, CONFIG_STORE_SCL_PIN);
    I2C.setClock(5000);
    i2c_eeprom_init(&I2C);
    i2c_eeprom_set_address(CONFIG_STORE_EEPROM_ADDRESS);
    i2c_eeprom_set_memory_size(CONFIG_STORE_EEPROM_SIZE);
    i2c_eeprom_set_page_size(CONFIG_STORE_EEPROM_PAGE_SIZE);

    if (i2c_eeprom_is_ready())
    {
        externalEEprom = true;
    }
    else
    {
        externalEEprom = false;
        EEPROM.begin(CONFIG_STORE_EEPROM_USED_SIZE);
    }
    config_store_read();
}

/**
 * Upgrades the Input config_store_t to the current version by
 * using default values.
 *
 * @param temp Reference to config_store_t to upgrade.
 */
void config_store_upgrade(config_store_t *temp)
{

    // Check if Storage of the Hardware part is necessary.
    // Write Version Number
#ifdef DEBUG
    Serial.printf("Upgrade Storage with from Version 0x%X to 0x%X\r\n", temp->psvn, CONFIG_STORE_PSVN);
#endif
    switch (temp->psvn)
    {
    case 0x6:
        memset(temp, 0, sizeof(config_store_t));
        temp->hardware_data.hardware_revision = 0x0;
        temp->hardware_data.serial_number = 0x7777;
        temp->user_settings.cone_id = 0x0;
        temp->user_settings.fallback_lightmode = 0x20;
        temp->user_settings.fallback_color = 0x8A;
        temp->user_settings.fallback_phase = 0x0;
        temp->user_settings.fallback_repetition_time = 0x0;

    case 0x1:
        temp->user_settings.turn_off_voltage_mv = 0;
        temp->user_settings.ip_address = 0x0000A8C0 |
                                         ((temp->hardware_data.serial_number & 0xFF) << 24) |
                                         ((temp->hardware_data.serial_number & 0xFF00) << 8); // 192.168.XX.XX
        temp->user_settings.subnet = 0x0000FFFF;
        temp->user_settings.gateway = 0x0100A8C0; // 192.168.0.1 in reversed order

    default:
        break;
    }
    temp->psvn = CONFIG_STORE_PSVN;
}

/**
 * Calculate the CRC for specific message.
 *
 * @param message Pointer to the message to be CRCed
 * @param length  Number of bytes to calculate
 *
 * @return Returns the CRC value.
 *
 */
uint32_t config_store_crc32b(uint8_t *message, uint16_t length)
{
    uint32_t byte, crc, mask;

    crc = 0xFFFFFFFF;
    for (int i = 0; i < length; i++)
    {
        byte = message[i]; // Get next byte.
        crc = crc ^ byte;
        for (int j = 7; j >= 0; j--)
        { // Do eight times.
            mask = -(crc & 1);
            crc = (crc >> 1) ^ (0xEDB88320 & mask);
        }
    }
    return ~crc;
}

/**
 * Read the config store from EEPROM
 *
 * @return Returns 0 when the storage is correctly loaded. Error code otherwise
 *
 */
int config_store_read(void)
{
    config_store_t temp;
    uint32_t crc;
    if (externalEEprom)
    {
        if (i2c_eeprom_read(CONFIG_STORE_EEPROM_HEADER_BASE_ADDRESS, (uint8_t *)&temp,
                            CONFIG_STORE_EEPROM_USED_SIZE))
        {
#ifdef DEBUG
            printf("Reading EEPROM failed\n!");
#endif
            return -1;
        }
    }
    else
    {
        EEPROM.get(CONFIG_STORE_EEPROM_HEADER_BASE_ADDRESS, temp);
    }

    if (temp.psvn != CONFIG_STORE_PSVN)
    {
#ifdef DEBUG
        printf("PSVN not matching. Upgrade will be performed.\r\n");
#endif
        config_store_upgrade(&temp);
        memcpy(&config_store, &temp, sizeof(config_store_t));
        config_store_storeHW();
        config_store_store();
        return 0;
    }

    crc = config_store_crc32b((uint8_t *)&temp.hardware_data, CONFIG_STORE_HARDWARE_DATA_SIZE);

    if (crc != temp.hardware_data_crc)
    {
#ifdef DEBUG
        printf("Hardware Data CRC not matching!\r\n %x != %x\r\n", crc, temp.hardware_data_crc);
#endif
        memcpy(&config_store, &temp, sizeof(config_store_t));
        return -2;
    }

    crc = config_store_crc32b((uint8_t *)&temp.user_settings, CONFIG_STORE_USER_SETTINGS_SIZE);

    if (crc != temp.user_settings_crc)
    {
#ifdef DEBUG
        printf("User Settings CRC not matching!\r\n");
#endif
        return -3;
    }
    memcpy(&config_store, &temp, sizeof(config_store_t));
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

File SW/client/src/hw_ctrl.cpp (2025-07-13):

/****************************)***************************************************/
/*
 * File: hw_ctrl.h
 * Author: Andreas Horat
 */
/*******************************************************************************/
/*
 * This file contains a simple driver for hardware functions (Turnoff and Hall)
 */
/*******************************************************************************/
#include "hw_ctrl.h"
#include "Arduino.h"

uint8_t hw_ctrl_kill_pin;
uint8_t hw_ctrl_hall_pin;

/**
 * Setups the HW Ctrl pins
 */
void hw_ctrl_setup(uint8_t hw_revision)
{
  switch (hw_revision)
  {
  case 1:
    hw_ctrl_hall_pin = HALL_PIN_NC1_1AA;
    hw_ctrl_kill_pin = KILL_PIN_NC1_1AA;
    break;
  case 2:
    hw_ctrl_hall_pin = HALL_PIN_NC1_1BB;
    hw_ctrl_kill_pin = KILL_PIN_NC1_1BB;
    break;

  default:
    break;
  }
  pinMode(hw_ctrl_kill_pin, OUTPUT);
  pinMode(hw_ctrl_hall_pin, INPUT);
}

uint8_t hw_ctrl_get_hall_state(void)
{
  return digitalRead(hw_ctrl_hall_pin);
}

/**
 * Turn off the Cone
 */
void hw_ctrl_turn_off(void)
{
  analogWriteFreq(10000);
  analogWrite(hw_ctrl_kill_pin, 128);
}

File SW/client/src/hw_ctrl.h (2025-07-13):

/****************************)***************************************************/
/* 
 * File: hw_ctrl.h
 * Author: Andreas Horat
 */
/*******************************************************************************/
/*
 * This file contains a simple driver for hardware functions (Turnoff and Hall)
 */
/*******************************************************************************/
#ifndef HW_CTRL
#define HW_CTRL
#include <stdint.h>
#define KILL_PIN_NC1_1AA 13
#define HALL_PIN_NC1_1AA 14
#define KILL_PIN_NC1_1BB 12
#define HALL_PIN_NC1_1BB 16

void hw_ctrl_setup(uint8_t hw_revision);

/**
 * Get the state of the hall sensor
 * 
 * @return True if Hall sensor is used.
 */
uint8_t hw_ctrl_get_hall_state(void);

/**
 * Turn off the Cone
 */
void hw_ctrl_turn_off(void);




#endif

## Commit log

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2023-08-11 Added resistors to gate of mosfet to limit current.
    [night-cones.kicad_sch]
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2024-01-09 Schematic ports and sheet entries synchronized, charging inputs added
    [[1] night-cone-proto0-Top.SchDoc, [2] Control.SchDoc, [3] FailSafe.SchDoc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]
2024-01-10 HW: Schematic prepared as far as possible without library access
    [[1] night-cone-proto0-Top.SchDoc, [2] Control.SchDoc, [3] FailSafe.SchDoc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]
2024-01-13 Added first LED Schematic entry, added Charger Circuit. Still missing some Protection
    [[4] LED.SchDoc, [5] Charger.SchDoc]
2024-01-13 PCB project structure prepared for LED schematic sheet
    [[1] night-cone-proto0-Top.SchDoc, [4] Lights.SchDoc, [6] Charger.SchDoc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]
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2024-01-14 Added Parts for Daniel in Failsafe Schematic
    [[3] FailSafe.SchDoc]
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2024-01-15 Some reformatting of Failsafe, LED and Power schematics
    [[3] FailSafe.SchDoc, [5] LED.SchDoc, [7] Power.SchDoc]
2024-01-15 Updated Power Sheet with correct voltage divider, BSS138 MOSFET and currect filter components at Charge
    [[7] Power.SchDoc]
2024-01-15 Updated all Schematic sheets with actualised supplier links, added BomDoc
    [[1] night-cone-proto0-Top.SchDoc, [2] Control.SchDoc, [3] FailSafe.SchDoc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]
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2024-01-15 FailSafe Schematic mostly completed
    [[3] FailSafe.SchDoc]
2024-01-16 Designators and comments cleaned up, 5V supply changed to 5.2V, general cleanup
    [[1] night-cone-proto0-Top.SchDoc, [2] Control.SchDoc, [3] FailSafe.SchDoc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]
2024-01-16 Bypass capacitors added to failsafe circuit
    [[3] FailSafe.SchDoc]
2024-01-16 Updated 1uF Capacitor, updated inductors, replaced wrong value components
    [[1] night-cone-proto0-Top.SchDoc, [2] Control.SchDoc, [3] FailSafe.SchDoc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]
2024-01-17 TLC555 oscillator analysis and measurement
    [2024-01-17_TLC555 oscillator.xlsx]
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2024-01-17 Multiple parts updated from library, Failsafe pulse generator timing adjusted to measurement results
    [[1] night-cone-proto0-Top.SchDoc, [2] Control.SchDoc, [3] FailSafe.SchDoc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]
2024-01-17 Update from library with SOP14, SOP16, SOT-363 and 2X4 header
    [[1] night-cone-proto0-Top.SchDoc, [2] Control.SchDoc, [3] FailSafe.SchDoc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]
2024-01-19 Schematic reannotated, placement of LEDs on PCB, components arranged in groups
    [[1] night-cone-proto0-Top.SchDoc, [2] Control.SchDoc, [3] FailSafe.SchDoc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]
2024-01-19 Updated TP4056, Added Note on control, Designed Kill switch filter
    [[2] Control.SchDoc, [6] Charger.SchDoc, [7] Power.SchDoc]
2024-01-20 Rough placement of Failsafe logic and Power supply
2024-01-20 Timing in LED table corrected
    [[5] LED.SchDoc]
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2024-01-22 Library reference of charger corrected
    [[6] Charger.SchDoc]
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2024-01-22 Updated Components that where newly added to use Basic parts
    [[3] FailSafe.SchDoc, [6] Charger.SchDoc, [7] Power.SchDoc]
2024-01-22 Update from library with LCSC part number and JLC part type parameters, Layout adjusted for larger footprints of JLC Basic Parts
    [[1] night-cone-proto0-Top.SchDoc, [2] Control.SchDoc, [3] FailSafe.SchDoc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]
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2024-01-22 Resistors and capacitors updated to JLC basic parts
    [[1] night-cone-proto0-Top.SchDoc, [2] Control.SchDoc, [3] FailSafe.SchDoc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]
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2024-01-23 Failsafe pulse generator adapted for different requirements of WS2813B-V5, Schematic reannotated, Footprint in WS2813 variant fixed
    [2024-01-17_TLC555 oscillator.xlsx, [3] FailSafe.SchDoc, [5] LED.SchDoc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]
2024-01-23 Removed various resistors from BOM count, added LEDs for Power
    [[2] Control.SchDoc, [3] FailSafe.SchDoc, [5] LED.SchDoc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]
2024-01-23 Top LEDs rearranged and routing prepared, All components apart from Bottom LEDs and their preripherals moved to top layer, Failsave rearranged
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2024-01-24 Gates swapped for better routing, Failsafe circuit routed
    [[3] FailSafe.SchDoc]
2024-01-24 Replaced capacitors and resistor to simplify BOM
    [[6] Charger.SchDoc, [7] Power.SchDoc]
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2024-01-24 Battery changed from J? to BAT?, reannotated, battery footprint updated from library
    [[1] night-cone-proto0-Top.SchDoc, [2] Control.SchDoc, [3] FailSafe.SchDoc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]
2024-01-25 Power supplies routed, ESP-12F added, LEDs moved to create spae for antenna keepout
    [[1] night-cone-proto0-Top.SchDoc, [2] Control.SchDoc, [7] Power.SchDoc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]
2024-01-26 Voltage divider for battery voltage measurement added, Hall sensor signal connected to controller, Programming connector removed, Component placement mostly finished, polygon pours added
    [[1] night-cone-proto0-Top.SchDoc, [2] Control.SchDoc, [4] Lights.SchDoc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]
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2024-01-27 Testpoints on GPIO9 and 10 removed, routing continued, 3V3 Polygon added
    [[2] Control.SchDoc]
2024-01-28 Routing completed, DRC errors fixed
    [night-cone-proto0.PrjPcb]
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2024-01-31 Panel finished, fiducials and tooling holes added, outjob adjusted
    [NC1-1A-PANEL.PcbDoc]
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2024-01-31 Chargin LED color changed to green to reduce cost for prototype
    [Charger.SchDoc]
2024-01-31 Failsafe counter output selection resistors removed
    [FailSafe.SchDoc]
2024-01-31 Panel adjusted to 2 by 2 single PCBs
    [NC1-1A-PANEL.PcbDoc]
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2024-01-31 Annotation updated, started to clean up assembly drawing
    [Charger.SchDoc, Control.SchDoc, FailSafe.SchDoc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]
2024-01-31 LED rotation corrected
    [LED.SchDoc, NC1-1AA.PrjPcb]
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2024-01-31 LEDs corrected, not populated components changed to standard (no BOM)
    [Charger.SchDoc, LED.SchDoc, NC1-1A-PANEL.PcbDoc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]
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2024-02-15 DOC: Small corrections, schematic added to appendix
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2024-02-24 DOC: Added description of Charger, BMS and added correction of Overcurrentprotection
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2024-02-24 HW: NC1-1AA PCB project copied to start work on index BA
    [Charger.SchDoc, Control.SchDoc, FailSafe.SchDoc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]
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2024-03-01 HW: Modifications from revision A, Component around LEDs placed directly underneath LEDs
    [Charger.SchDoc, Control.SchDoc, FailSafe.SchDoc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]
2024-03-03 Changes at housing cad files. Decreased wall thickness and added gussets. Added space for antenna to top part.
    [night-cone_middle.prt, night-cone_top.prt]
2024-03-06 HW: Testpoints removed from end of LED chain, filter capacitor added to voltage measurement, ESP module moved slightly, all LEDs placed
    [Charger.SchDoc, Control.SchDoc, FailSafe.SchDoc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]
2024-03-11 HW: Additional hall sensor added to enable turning the NightCone on and off with a magnet
    [Control.SchDoc, NC1-1BA.PrjPcb, Power.SchDoc]
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2024-03-15 HW: Programming connector changed to double-sided TAG-CONNECT, Testpoints for RX and TX
    [Control.SchDoc, NC1-1BA.PrjPcb]
2024-03-15 HW: Failsafe oscillator measurements continued
    [2024-01-17_TLC555 oscillator.xlsx]
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2024-03-22 HW: On/Off controller feedback capacitor removed, testpoint labels adjusted, Signal DATA_FAILSAFE renamed to DATA_FS
    [FailSafe.SchDoc, Lights.SchDoc, NC1-1-Top.SchDoc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]
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2024-04-18 HW: Formula for circuit 2 in temperature measurement analysis script corrected
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2024-04-22 HW: Second hall sensor added to enable on and off by magnet, position of hall sensors finalized, 5V2 converter moved
    [NC1-1BA.PrjPcb, Power.SchDoc]
2024-04-25 HW: +3V3 converter and programming connector moved up, temperature measurement placed, EEPROM moved, HW identification resistors placed, routing completed, testpoint labels organized, testpoint label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
    [Charger.SchDoc, Control.SchDoc, NC1-1BA.PrjPcb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]
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2024-04-30 HW: Voltage divider values for temperature measurement updated
    [Control.SchDoc, NC1-1BA.PrjPcb]
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2024-05-04 HW: Testpoint added for RST pin to allow programming through testpoints
    [Charger.SchDoc, Control.SchDoc, FailSafe.SchDoc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]
2024-05-07 HW: Series resistor added to HALL/ signal to allow signal to be pulled low by the testpoint
    [NC1-1BA.PrjPcb, Power.SchDoc]
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2024-05-09 HW: Hall sensor swapped to unipolar MT8691, series resistor added to DATA signal to allow a signal generator to overpower the GPIO pin, WP pin of EEPROM connected to GND
    [Charger.SchDoc, Control.SchDoc, FailSafe.SchDoc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]
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2024-05-27 Updated WS8814 becuase of wrong order code
    [Charger.SchDoc, NC1-1BA.PrjPcb]
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2024-05-29 Added missing documents from first commissioning
    [Quiescent_Current.csv]
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2024-06-12 HW: Test: Pass/Fail testing added to Report and Device
    [Device.py, Report.py]
2024-06-13 HW: Test: Card list changed to dictionary in order to be able to call them by name, Short circuit test and charging test implemented
    [NC1-1.py, SwitchUnit.py]
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2024-06-14 HW: Test: Voltage measurement card pinout corrected, syntax errors corrected, Discharge capacitors before short testing for more consistent values, Limits for short testing adjusted
    [NC1-1.py]
2024-06-23 HW: Test: Overall pass-fail with printout when failed added to device
    [Device.py]
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2024-09-14 Removed all compile Errors
    [adc.cpp, config_store.cpp, led.cpp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]
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2024-10-06 CSW: I make it short. Many comments, many testing, almost everything working now.
    [adc.cpp, adc.h, cli.cpp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]
2024-10-06 DOC: Shorted R3 and pull-up on I2C lines added to modifications
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2024-12-08 Fixed Error in Naming and tested Temperature
    [led.cpp, main.cpp, wifi.cpp]
2024-12-13 Minor fixes in the software and improved programmer
    [cli.cpp, config_store.cpp, wifi.cpp]
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2024-12-18 Updated Kill simulation script with planned fix, added missing frames detection
    [wifi.cpp]
2025-01-05 Fixed Errors in Config store detected during comissioning
    [config_store.cpp, i2cEeprom.cpp]
2025-01-05 Added additional virtual LED to trigger failsafe, when cone is dark. Fixed some Errors
    [led.cpp, main.cpp, wifi.cpp]
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2025-03-18 Fixed Errors from Previous commit
    [cli.cpp, config_store.cpp, main.cpp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]
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2025-07-24 HW: Modifications for I2C pull-up resistors and software shutoff added to NC1-1BB
    [NC1-1B-BASIS.PcbDoc, Power.SchDoc]
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
